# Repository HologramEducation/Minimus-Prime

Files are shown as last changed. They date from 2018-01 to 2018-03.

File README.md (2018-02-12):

# Minimus-Prime

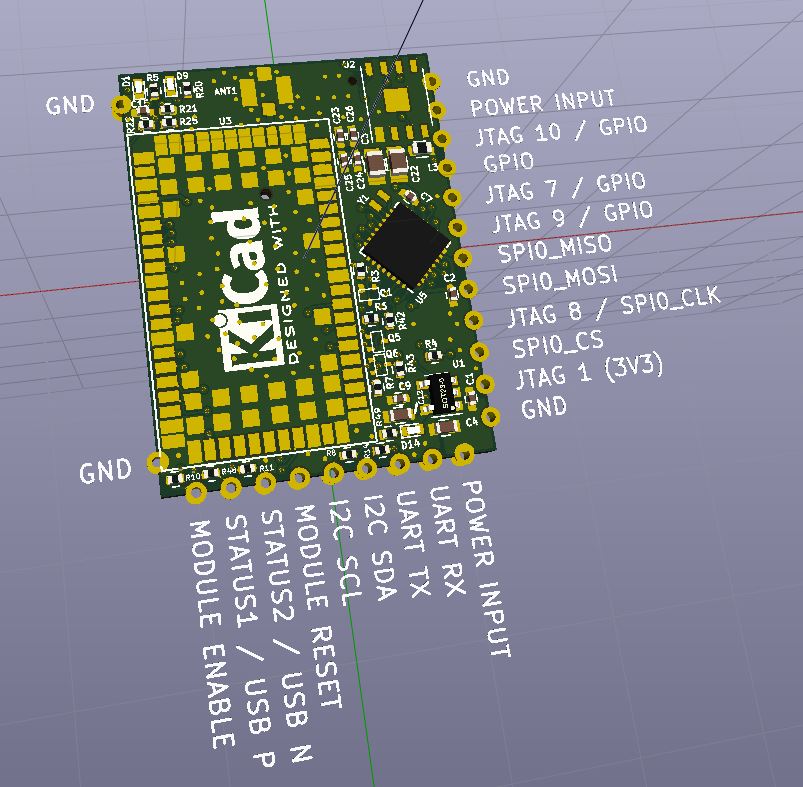
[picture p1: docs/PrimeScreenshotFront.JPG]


## Background

This is an experiment to shrink the logic and support circuitry around a cellular modem to the bare minimum and offer them as a surface mount solderable board. This design will be tested as a lightweight hardware device to connect to Hologram services.

### License

This design is OSHW

## Usage

This device is meant to work with uBlox cellular modems and the Hologram Global SIM card. To get a free SIM and 1 MB of data per month on the cellular plan, check out the [Developer Plan](https://hologram.io/devplan/)

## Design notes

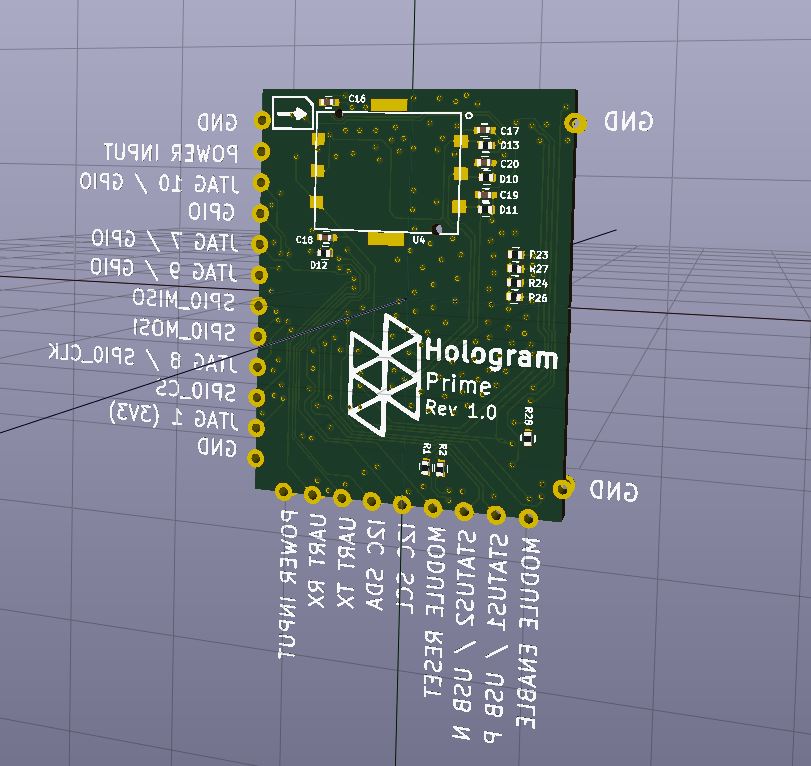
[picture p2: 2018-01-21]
docs/PrimeScreenshotBack.JPG

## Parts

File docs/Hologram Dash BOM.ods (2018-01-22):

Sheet: DASH BOM APPROVAL
SEQ | BID EX | MANUFACTURER P/N | NEDA | MFR | QTY PER
1 | R | A-1JB | 6812 | Amphenol | 1
2 | RN | B2B-PH-SM4-TB(LF)(SN) | NF | JST | 1
3 | R | GRM155R61C104KA88D | 2606 | MURATA | 15
4 | R | 04026D105KAT2A | 7710 | AVX | 3
5 | R | GRM188R71C105KA12D | 2606 | MURATA | 1
6 | R | CL10A225MQ8NNNC | 4139 | SAMSUNG | 4
7 | R | GRM155R71C103KA01D | 2606 | MURATA | 2
8 | R | GRM188R60J106ME84D | 2606 | Murata | 2
9 | R | 04025A150JAT2A | 7710 | AVX/ELCO | 1
10 | R | GRM188R60J226MEA0D | 2606 | MURATA | 3
11 | R | 04025A470JAT2A | 7710 | AVX | 4
12 | R | C0402C560J5GACTU | 7429 | KEMET | 1
13 | R | F950J337MBAAQ2 | 7710 | AVX | 1
14 |  | CX2016DB16000D0WZRC1 | 1412 | AVX | 1
15 | R | ABS05-32.768KHZ-T | 4217 | Abracon | 2
16 |  | CDBQR0230L | 5870 | Comchip | 1
17 | R | CRS08(TE85L,Q,M) | 1062 | Toshiba Semiconductor and Storage | 2
18 | R | BLM18AG121SN1D | 2606 | Murata | 4
19 |  | MKL17Z256VFM4 | 3691 | FREESCALE | 1
20 | R | SF-0603S300-2 | 1506 | Bourns | 1
21 | RN | XFL4020-102MEC | NF | Coilcraft | 1
22 | R | VLMW1500-GS08 | 5680 | VISHAY | 2
23 | * CAN'T GUARANTEE WE WILL BE ABLE TO BUY PART FROM SUPPLIER DUE TO ALLOCATION ISSUES RN | SMLP34RGB2W3 | NF | Rohm | 1
24 | No bid, non book item not availabe to re-sellers | MAX17043G+U | NF | Maxim | 1
25 |  | MCP73871-2CCI/ML | 1389 | MICROCHIP | 1
26 |  | MK22FN1M0AVLH12 | 3691 | Freescale | 1
27 | R | NCP177AMX330TCG | 5236 | On Semi | 1
28 | R | PESD0402-140 | 3685 | Littlefuse | 7
29 | # | 22284180 | 3303 | MOLEX | 2
30 | R | ERJ-2GE0R00X | 1386 | PANASONIC | 1
31 | R | RC0402JR-071KL | 5823 | YAEGO | 1
32 | R | RC0402FR-071ML | 5823 | YAEGO | 1
33 | R | RC0402FR-072KL | 5823 | YAEGO | 1
34 | R | RC0402JR-0710KL | 5823 | YAEGO | 8
35 | R | RC0402FR-0722RL | 5823 | YAEGO | 2
36 | R | RC0402FR-0762KL | 5823 | YAEGO | 1
37 | R | RC0402FR-0775RL | 5823 | YAEGO | 2
38 | R | ERJ-2GEJ104X | 1386 | PANASONIC | 1
39 | R | ERJ-2GEJ121X | 1386 | PANASONIC | 1
40 | R | RC0402FR-07150KL | 5823 | YAEGO | 1
41 | R | ERJ-2GEJ161X | 1386 | PANASONIC | 1
42 | R | ERJ-2GEJ471X | 1386 | PANASONIC | 2
43 | RN | SARA-U260-00S | NF | U-BLOX | 1
44 | RN | SIM8050-6-0-14-01-A | NF | GLOBAL CONNECTOR TECHNOLOGY | 1
45 | R | PTS810SJM250SMTRLFS | 9444 | C&K Components | 2
46 | R | TPS22945DCKR | 7713 | Texas Instruments | 1
47 | R# | TPS63020DSJR | 7713 | TI | 1
48 | R | 10118193-0001LF | 8314 | Amphenol FCI | 1
49 | R | SN74AVC4T774RSVR | 7713 | TI | 1
50 | N# | Hologramh REV 1P2 | NF | PALPILOT | 1
 |  | I have reviewed the Arrow Bill of Material and accept it as
 |  | complete and accurate.
 |  | I have reviewed Arrow Bill of Material and have made
 |  | changes / revisions per the attached. Upon completion
 |  | of said changes / revisions, I accept Arrow Bill of
 |  | Material as complete and accurate. (NOTE: Changes or
 |  | revisions may alter the price and delivery of this proposal.)
 |  | I have reviewed and accept all bid exceptions as indicated
 |  | on Arrow Electronics' Bill of Material.
 |  | # | These items are considered to be acceptable
 |  |  | alternatives to the Approved Vendor List
 |  | N | These items , purchased pursuant to my provided
 |  |  | purchase orders / forecast are designated NCNR
 |  |  | Non-Cancelable Non-Returnable.
 |  | R | These items are to be provided in reeled form.
 |  |  | Residual reeled product due to cancelation or
 |  |  | ECO activity will be NCNR.
 |  | P | These items are to be programmed and are NCNR.
_____________________

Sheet: NOVA BOM APPROVAL
 |  | AMSS Advanced Manufacturing Support Services |  |  |  | Bid Exceptions Key
 |  | BOM APPROVAL |  |  |  | N | NCNR
 |  | HOLOGRAM |  |  |  | R | TAPE & REEL
 |  | BOM HOLOGRAM MODEM REV J |  |  |  | P | PROGRAMMED
 |  |  |  |  |  | # | Different part number than called out on AVL
 |  |  |  |  |  | COP | SUPPLIED BY CUSTOMER AT NO VALUE TO THE BILL OF MATERIALS
CUSTOMER # | SEQ | BID EX | MANUFACTURER P/N | NEDA | MFR | QTY PER | L/T | MIN
CON-0006 | 1 | R | A-1JB | 6812 | Amphenol | 1 | 24 | 50000
CAP-0004 | 2 | R | GRM155R61C104KA88D | 2606 | MURATA | 3 | 38 | 10000
CAP-0002 | 3 | R | CL10A225MQ8NNNC | 4139 | SAMSUNG | 1 | 16 | 4000
CAP-0016 | 4 | R | GRM155R71C103KA01D | 2606 | MURATA | 3 | 14 | 10000
CAP-0007 | 5 | R | GRM188R60J106ME84D | 2606 | Murata | 1 | 16 | 4000
CAP-0011 | 6 | R | 04025A150JAT2A | 7710 | AVX/ELCO | 3 | 20 | 10000
CAP-0008 | 7 | R | GRM188R60J226MEA0D | 2606 | MURATA | 3 | 38 | 4000
CAP-0010 | 8 | R | 04025A470JAT2A | 7710 | AVX | 4 | 20 | 30000
CAP-0009 | 9 | R | C0402C560J5GACTU | 7429 | KEMET | 3 | 8 | 10000
CAP-0012 | 10 | R | F950J337MBAAQ2 | 7710 | AVX | 3 | 9 | 2000
IND-0005 | 11 | R | BLM18KG121TN1D | 2606 | Murata | 1 | 6 | 4000
IND-0003 | 12 | RN | XFL4020-102MEC | NF | Coilcraft | 1 | STK-6 | 1000
DIO-0007 | 13 | R | VLMB1500-GS08 | 5680 | VISHAY | 1 | 12 | 9000
DIO-0008 | 14 | R | VLMS1500-GS08 | 5680 | VISHAY | 1 | 10 | 9000
DIO-0009 | 15 | R | PESD0402-140 | 3685 | Littlefuse | 7 | 8 | 10000
RES-0020 | 16 | R | RC0603JR-070RL | 5823 | YAEGO | 1 | 18 | 5000
RES-0014 | 17 | R | RC0402FR-071ML | 5823 | YAEGO | 1 | 8 | 50000
RES-0019 | 18 | R | RC0402FR-073KL | 5823 | YAEGO | 2 | 18 | 50000
RES-0008 | 19 | R | RC0402JR-0710KL | 5823 | YAEGO | 4 | 18 | 50000
RES-0016 | 20 | R | RC0402FR-0722RL | 5823 | YAEGO | 2 | 18 | 50000
RES-0003 | 21 | R | ERJ-2GEJ104X | 1386 | PANASONIC | 1 | 54 | 50000
RES-0004 | 22 | R | RC0402FR-07150KL | 5823 | YAEGO | 1 | 18 | 50000
RES-0006 | 23 | R | ERJ-2GEJ471X | 1386 | PANASONIC | 1 | 54 | 50000
IC-0007 | 24 | RN | SARA-U260-00S | NF | U-BLOX | 1 | STK-17 | 250
CON-0007 | 25 | RN | SIM8050-6-0-14-01-A | NF | GLOBAL CONNECTOR TECHNOLOGY | 1 | STK-10 | 1500
IC-0013 | 26 | R# | TPS63020DSJR | 7713 | TI | 1 | 12 | 3000
IC-0014 | 27 | R | MMBT3904LT1G | 8614 | ON Semiconductor | 4 | 45 | 3000
CON-0008 | 28 | R | 480372200 | 3303 | MOLEX | 1 | 6 | 7200
PCB | 29 | N# | Hologram_Nova REV J | NF | PALPILOT | 1 | 7 | 1008
{Initial one} |  |  | I have reviewed the Arrow Bill of Material and accept it as
______________ |  |  | complete and accurate.
______________ |  |  | I have reviewed Arrow Bill of Material and have made
 |  |  | changes / revisions per the attached. Upon completion
 |  |  | of said changes / revisions, I accept Arrow Bill of
 |  |  | Material as complete and accurate. (NOTE: Changes or
 |  |  | revisions may alter the price and delivery of this proposal.)
BID EXCEPTIONS: These items must be reviewed and approved. {Initial}
______________ |  |  | I have reviewed and accept all bid exceptions as indicated
 |  |  | on Arrow Electronics' Bill of Material.
 |  |  | # | These items are considered to be acceptable
 |  |  |  | alternatives to the Approved Vendor List
 |  |  | N | These items , purchased pursuant to my provided
 |  |  |  | purchase orders / forecast are designated NCNR
 |  |  |  | Non-Cancelable Non-Returnable.
 |  |  | R | These items are to be provided in reeled form.
 |  |  |  | Residual reeled product due to cancelation or
 |  |  |  | ECO activity will be NCNR.
 |  |  | P | These items are to be programmed and are NCNR.
___________________________________
Signature
___________________________________
Title
Date: | _____________________
PLEASE INCLUDE ALL PAGES WHEN RETURNING THE ATTACHMENT B.
ANY INFORMATION SUPPLIED BY ARROW IN RELATION TO A PARTICULAR PART'S ROHS/LEAD-FREE COMPLIANCE OR NON-COMPLIANCE IS PROVIDED "AS-IS" WITHOUT ANY WARRANTY WHATSOEVER, SUCH AS ALL WARRANTIES IMPLIED IN LAW, INCLUDING THE WARRANTIES OF MERCHANTABILITY AND SUITABILITY FOR A PARTICULAR PURPOSE. USE OF THE DATA IS AT CUSTOMER'S SOLE RISK.

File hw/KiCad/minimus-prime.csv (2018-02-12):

Refs | Link | MPN | Populated | datasheet | footprint | value
ANT1 | https://www.digikey.com/product-detail/en/amphenol-rf-division/A-1JB/ARF1579CT-ND/1196264 | A-1JB | Y |  | beaglephone-pocket:A-1JB | A-1JB
C1, C2, C7, C9, C16, C24 | https://www.digikey.com/product-detail/en/murata-electronics-north-america/GRM155R71C104KA88J/490-6328-1-ND/3845525 | GRM155R71C104KA88J | Y |  | Capacitors_SMD:C_0402 | 100n
C4, C12 | https://www.digikey.com/product-detail/en/murata-electronics-north-america/GRM188R60J226MEA0D/490-7611-1-ND/4280544 | GRM188R60J226MEA0D | Y |  | Capacitors_SMD:C_0603 | 22U
C15, C17-C20 | https://www.digikey.com/product-detail/en/murata-electronics-north-america/GRM1555C1H470JA01D/490-5942-1-ND/3721299 | GRM1555C1H470JA01 | N |  | Capacitors_SMD:C_0402 | 47p
C3, C22 | https://www.digikey.com/product-detail/en/samsung-electro-mechanics/CL21A226MOCLRNC/1276-6780-1-ND/5961639 | CL21A226MOCLRNC | Y |  | Capacitors_SMD:C_0805 | 22U
C23 | https://www.digikey.com/product-detail/en/murata-electronics-north-america/GRM1555C1H100JA01D/490-5921-1-ND/3721278 | GRM1555C1H100JA01D | Y |  | Capacitors_SMD:C_0402 | 10n
C25 | https://www.digikey.com/product-detail/en/murata-electronics-north-america/GRM1555C1H560JA01D/490-1288-1-ND/587890 | GRM1555C1H560JA01D | Y |  | Capacitors_SMD:C_0402 | 56p
C26 | https://www.digikey.com/product-detail/en/murata-electronics-north-america/GJM1555C1H150JB01D/490-3117-1-ND/702383 | GJM1555C1H150JB01D | Y |  | Capacitors_SMD:C_0402 | 15p
D1, D14 | https://www.digikey.com/product-detail/en/vishay-semiconductor-opto-division/VLMS1500-GS08/VLMS1500-GS08CT-ND/3504675 | VLMS1500-GS08 | Y |  | LEDs:LED_0402 | Red LED
D10-D13 | https://www.digikey.com/product-detail/en/littelfuse-inc/PESD0402-140/PESD0402-140CT-ND/1968526 | PESD0402-140 | N |  | Resistors_SMD:R_0402 | PESD0402
D9 | https://www.digikey.com/product-detail/en/vishay-semiconductor-opto-division/VLMB1500-GS08/VLMB1500-GS08TR-ND/3504677 | VLMB1500-GS08 | Y |  | LEDs:LED_0402 | Blue LED
J1 |  |  | N |  |  | Minimus_Prime_Outline
L3 | https://www.digikey.com/product-detail/en/murata-electronics-north-america/BLM18AG121SN1D/490-1011-1-ND/584459 | BLM18AG121SN1D | Y |  | Resistors_SMD:R_0603 | FB
Q1, Q5, Q6 | https://www.digikey.com/product-detail/en/central-semiconductor-corp/CMUDM7004-TR/CMUDM7004-CT-ND/5324586 | CMUDM7004 | Y | https://www.centralsemi.com/get_document.php?cmp=1&mergetype=pd&mergepath=pd&pdf_id=CMUDM7004.PDF | minimus-prime:SOT-523 | CMUDM7004
R1, R2, R23, R24, R26, R27, R28 | https://www.digikey.com/product-detail/en/yageo/RC0402JR-070RL/311-0.0JRCT-ND/729353 | RC0402JR-070RL | N |  | Resistors_SMD:R_0402 | 0
R4, R10, R11, R48 | https://www.digikey.com/product-detail/en/yageo/RC0402JR-070RL/311-0.0JRCT-ND/729353 | RC0402JR-070RL | Y |  | Resistors_SMD:R_0402 | 0
R6-R8, R14, R42, R43 | https://www.digikey.com/product-detail/en/yageo/RC0402JR-0710KL/311-10KJRTR-ND/726418 | RC0402JR-0710KL | Y |  | Resistors_SMD:R_0402 | 10K
R5, R20, R49 | https://www.digikey.com/product-detail/en/yageo/RC0402JR-073KL/311-3.0KJRCT-ND/729400 | RC0402JR-073KL | Y |  | Resistors_SMD:R_0402 | 3K
R21, R22 | https://www.digikey.com/product-detail/en/yageo/RC0402FR-07100KL/311-100KLRCT-ND/729473 | RC0402FR-07100KL | N |  | Resistors_SMD:R_0402 | 100K
R3, R25 | https://www.digikey.com/product-detail/en/yageo/RC0402FR-07100KL/311-100KLRCT-ND/729473 | RC0402FR-07100KL | Y |  | Resistors_SMD:R_0402 | 100K
TP1 |  |  | N |  |  | TEST
U1 | https://www.digikey.com/product-detail/en/texas-instruments/TLV70033DDCR/296-27937-1-ND/2440840 | TLV70033DDCR | Y | http://www.ti.com/lit/ds/slvsa00e/slvsa00e.pdf | TO_SOT_Packages_SMD:SOT-23-5 | TLV700
U2 |  | eSIM | Y |  | Housings_DFN_QFN:DFN-8-1EP_6x5mm_Pitch1.27mm_SmallFlag | eSIM
U3 | https://www.digikey.com/product-detail/en/u-blox-america-inc/SARA-U260-00S/672-1022-1-ND/6150685 | SARA-U260-00S | Y |  | beaglephone-pocket:SARA-G3-U2 | SARA-U260
U4 | http://www.newark.com/global-connector-technology/sim8050-6-0-14-01-a/connector-nano-sim-card-6-position/dp/94W2768 | SIM8050-6-0-14-01-A | N | http://www.farnell.com/datasheets/2342939.pdf | beaglephone-pocket:SIM8050-6-0-14-01-A | SIM-CARD-HOLDER
U5 | https://www.digikey.com/product-detail/en/nxp-usa-inc/MKL17Z256VFM4/MKL17Z256VFM4-ND/4988915 | MKL17Z256VFM4 | Y | http://cache.freescale.com/files/32bit/doc/data_sheet/KL17P64M48SF6.pdf | Housings_DFN_QFN:QFN-32-1EP_5x5mm_Pitch0.5mm | MKL17Z256VFM4
Y1 | https://www.digikey.com/product-detail/en/abracon-llc/ABS05-32.768KHZ-T/535-11899-1-ND/3508067 | ABS05-32.768KHZ-T | Y | http://www.abracon.com/Resonators/ABS05.pdf | minimus-prime:ABS05 | ABS5

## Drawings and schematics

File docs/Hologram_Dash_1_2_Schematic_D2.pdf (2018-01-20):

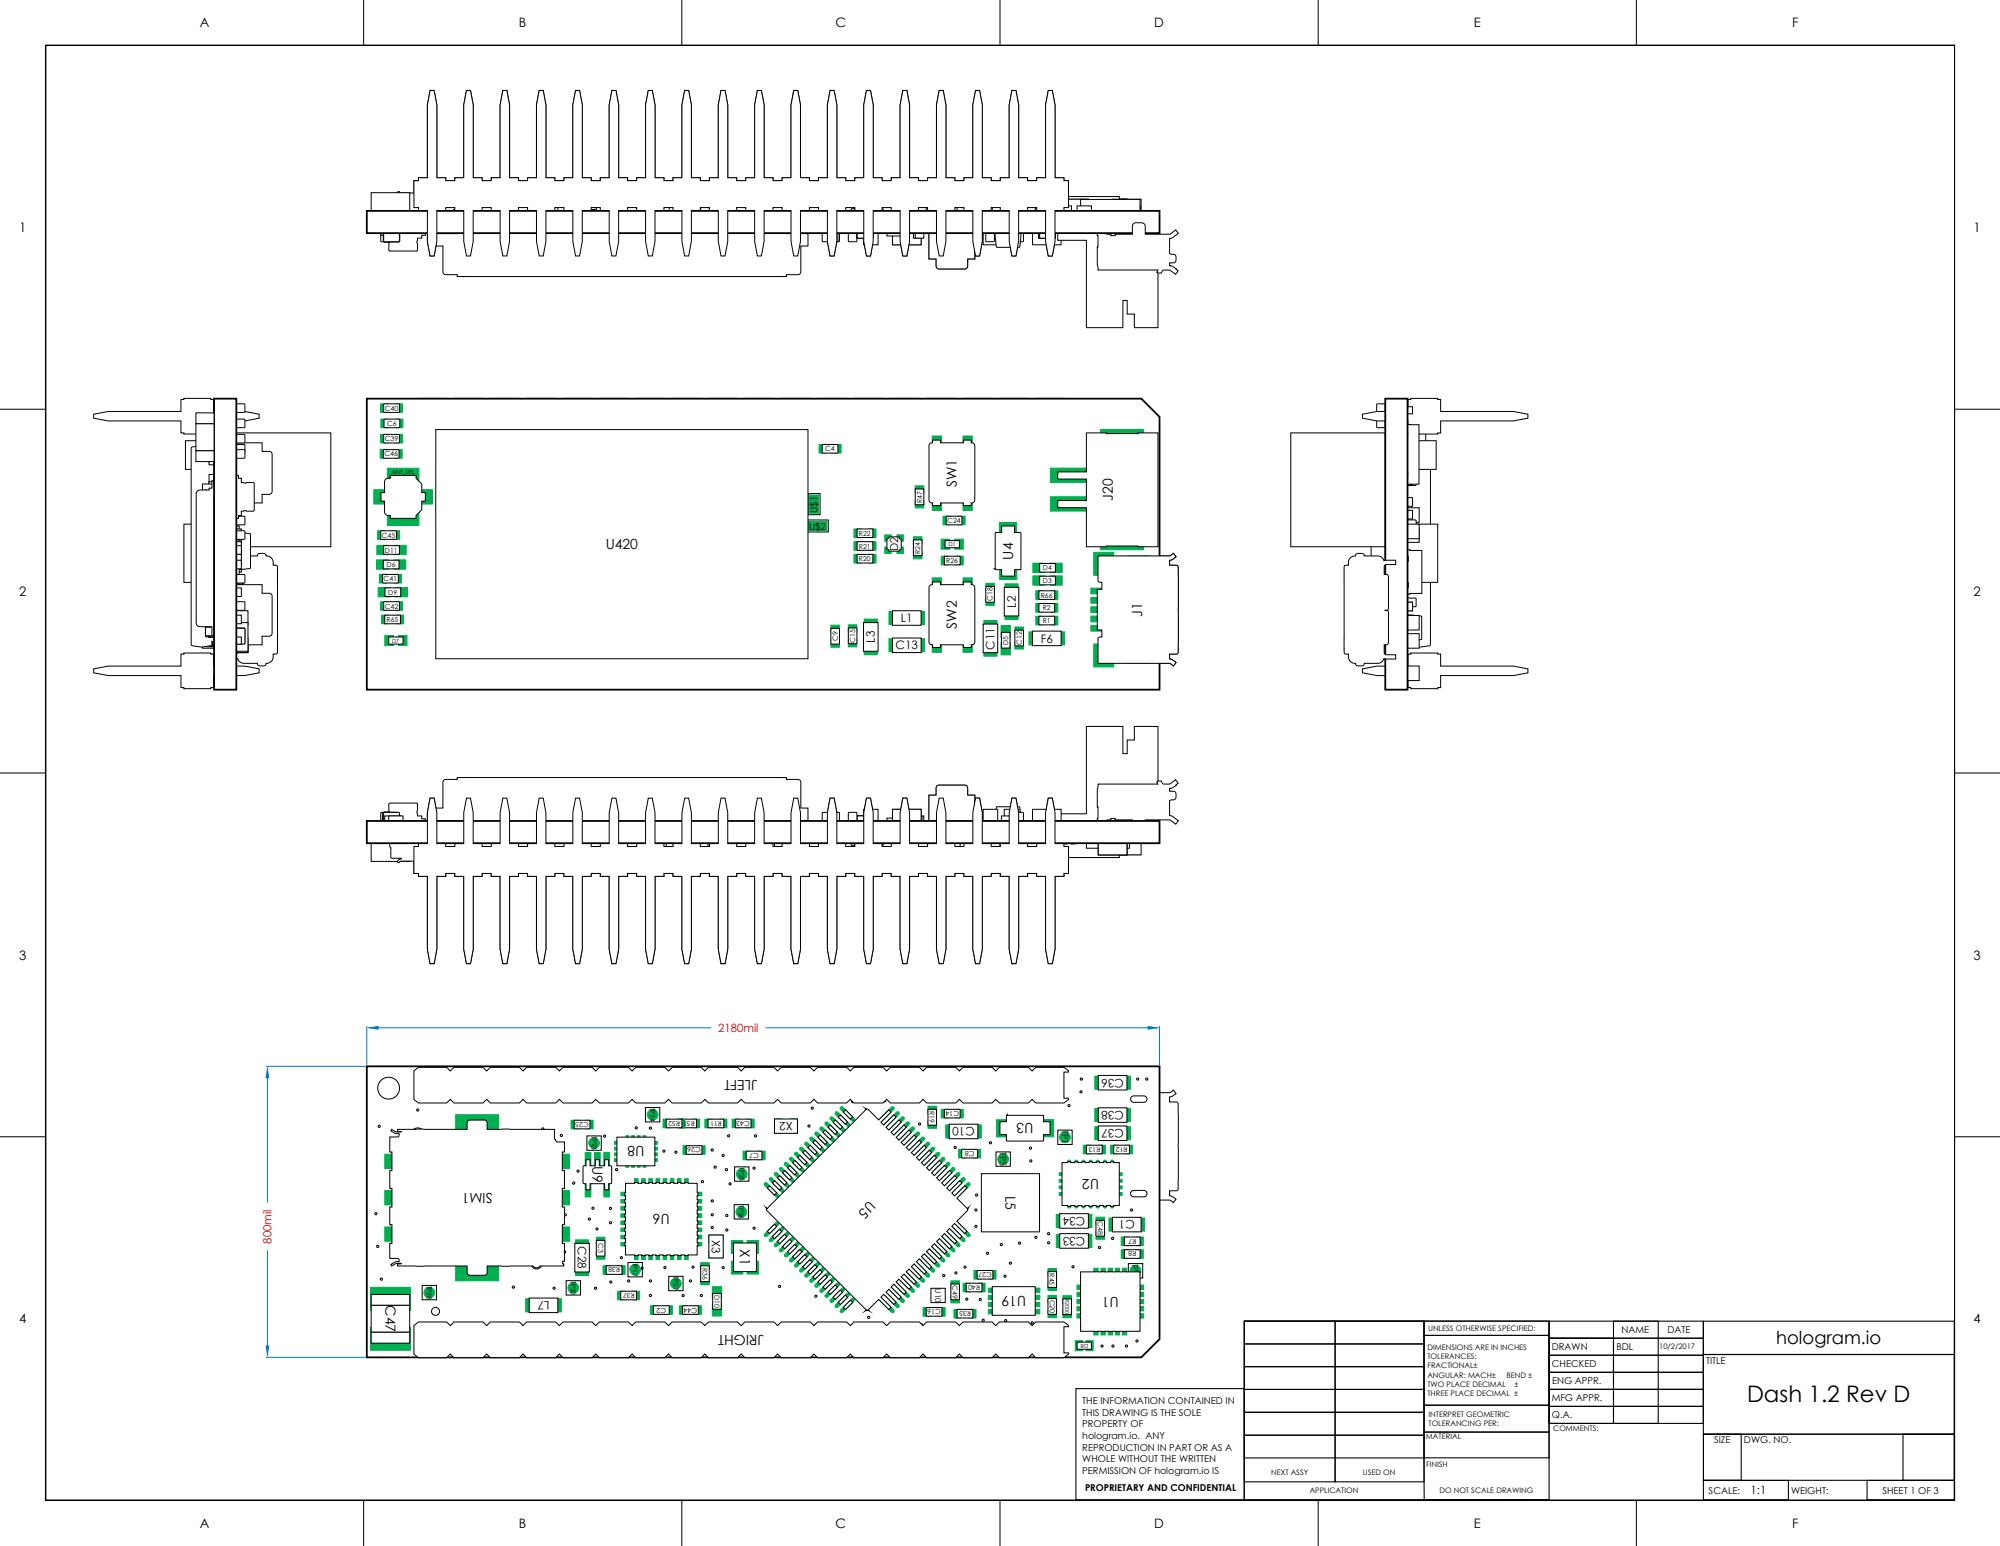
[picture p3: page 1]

DIMENSIONS ARE IN INCHES
TOLERANCES:
FRACTIONAL±
ANGULAR: MACH± BEND ±
TWO PLACE DECIMAL ±
THREE PLACE DECIMAL ±

THE INFORMATION CONTAINED IN
THIS DRAWING IS THE SOLE
PROPERTY OF
hologram.io. ANY
REPRODUCTION IN PART OR AS A
WHOLE WITHOUT THE WRITTEN
PERMISSION OF hologram.io IS
PROPRIETARY AND CONFIDENTIAL

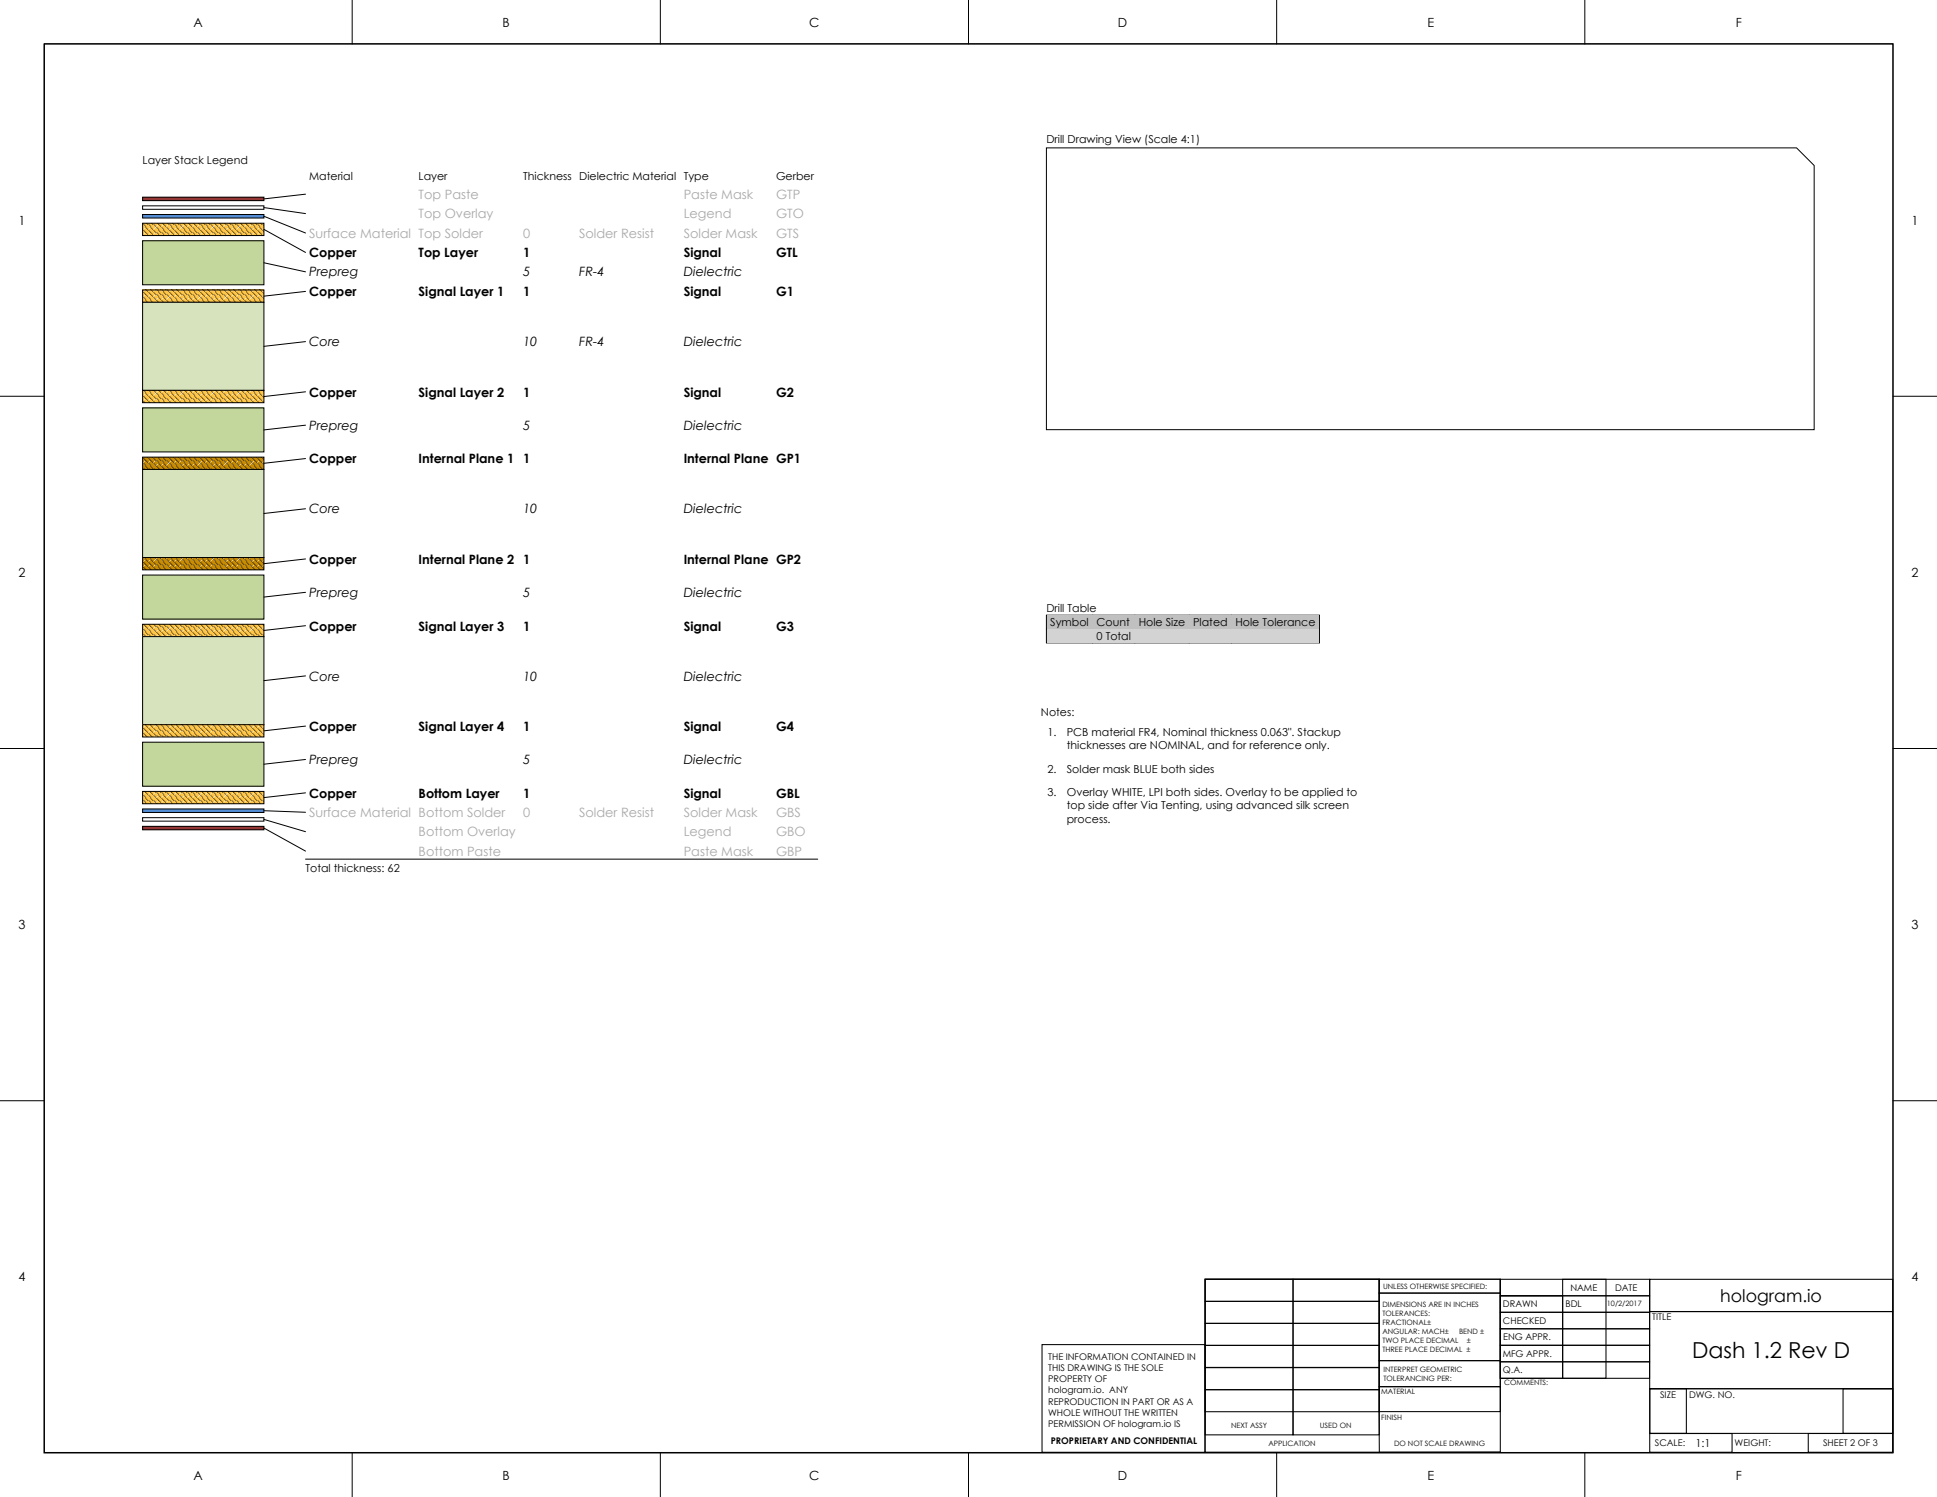
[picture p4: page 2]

Drill Drawing View (Scale 4:1)

Symbol | Count | Hole Size | Plated | Hole Tolerance

0 Total

Notes:
PCB material FR4, Nominal thickness 0.063". Stackup
thicknesses are NOMINAL, and for reference only.
2. Solder mask BLUE both sides
Overlay WHITE, LPI both sides. Overlay to be applied to
top side after Via Tenting, using advanced silk screen
process.

UNLESS OTHERWISE SPECIFIED: | | NAME | DATE 10/2/2017 | hologram.io
DIMENSIONS ARE IN INCHES TOLERANCES: FRACTIONAL± ANGULAR: MACH± BEND ± TWO PLACE DECIMAL ± THREE PLACE DECIMAL ± | DRAWN | BDL

CHECKED | | | TITLE Dash 1.2 Rev D
ENG APPR.

THE INFORMATION CONTAINED IN THIS DRAWING IS THE SOLE | | | MFG APPR.

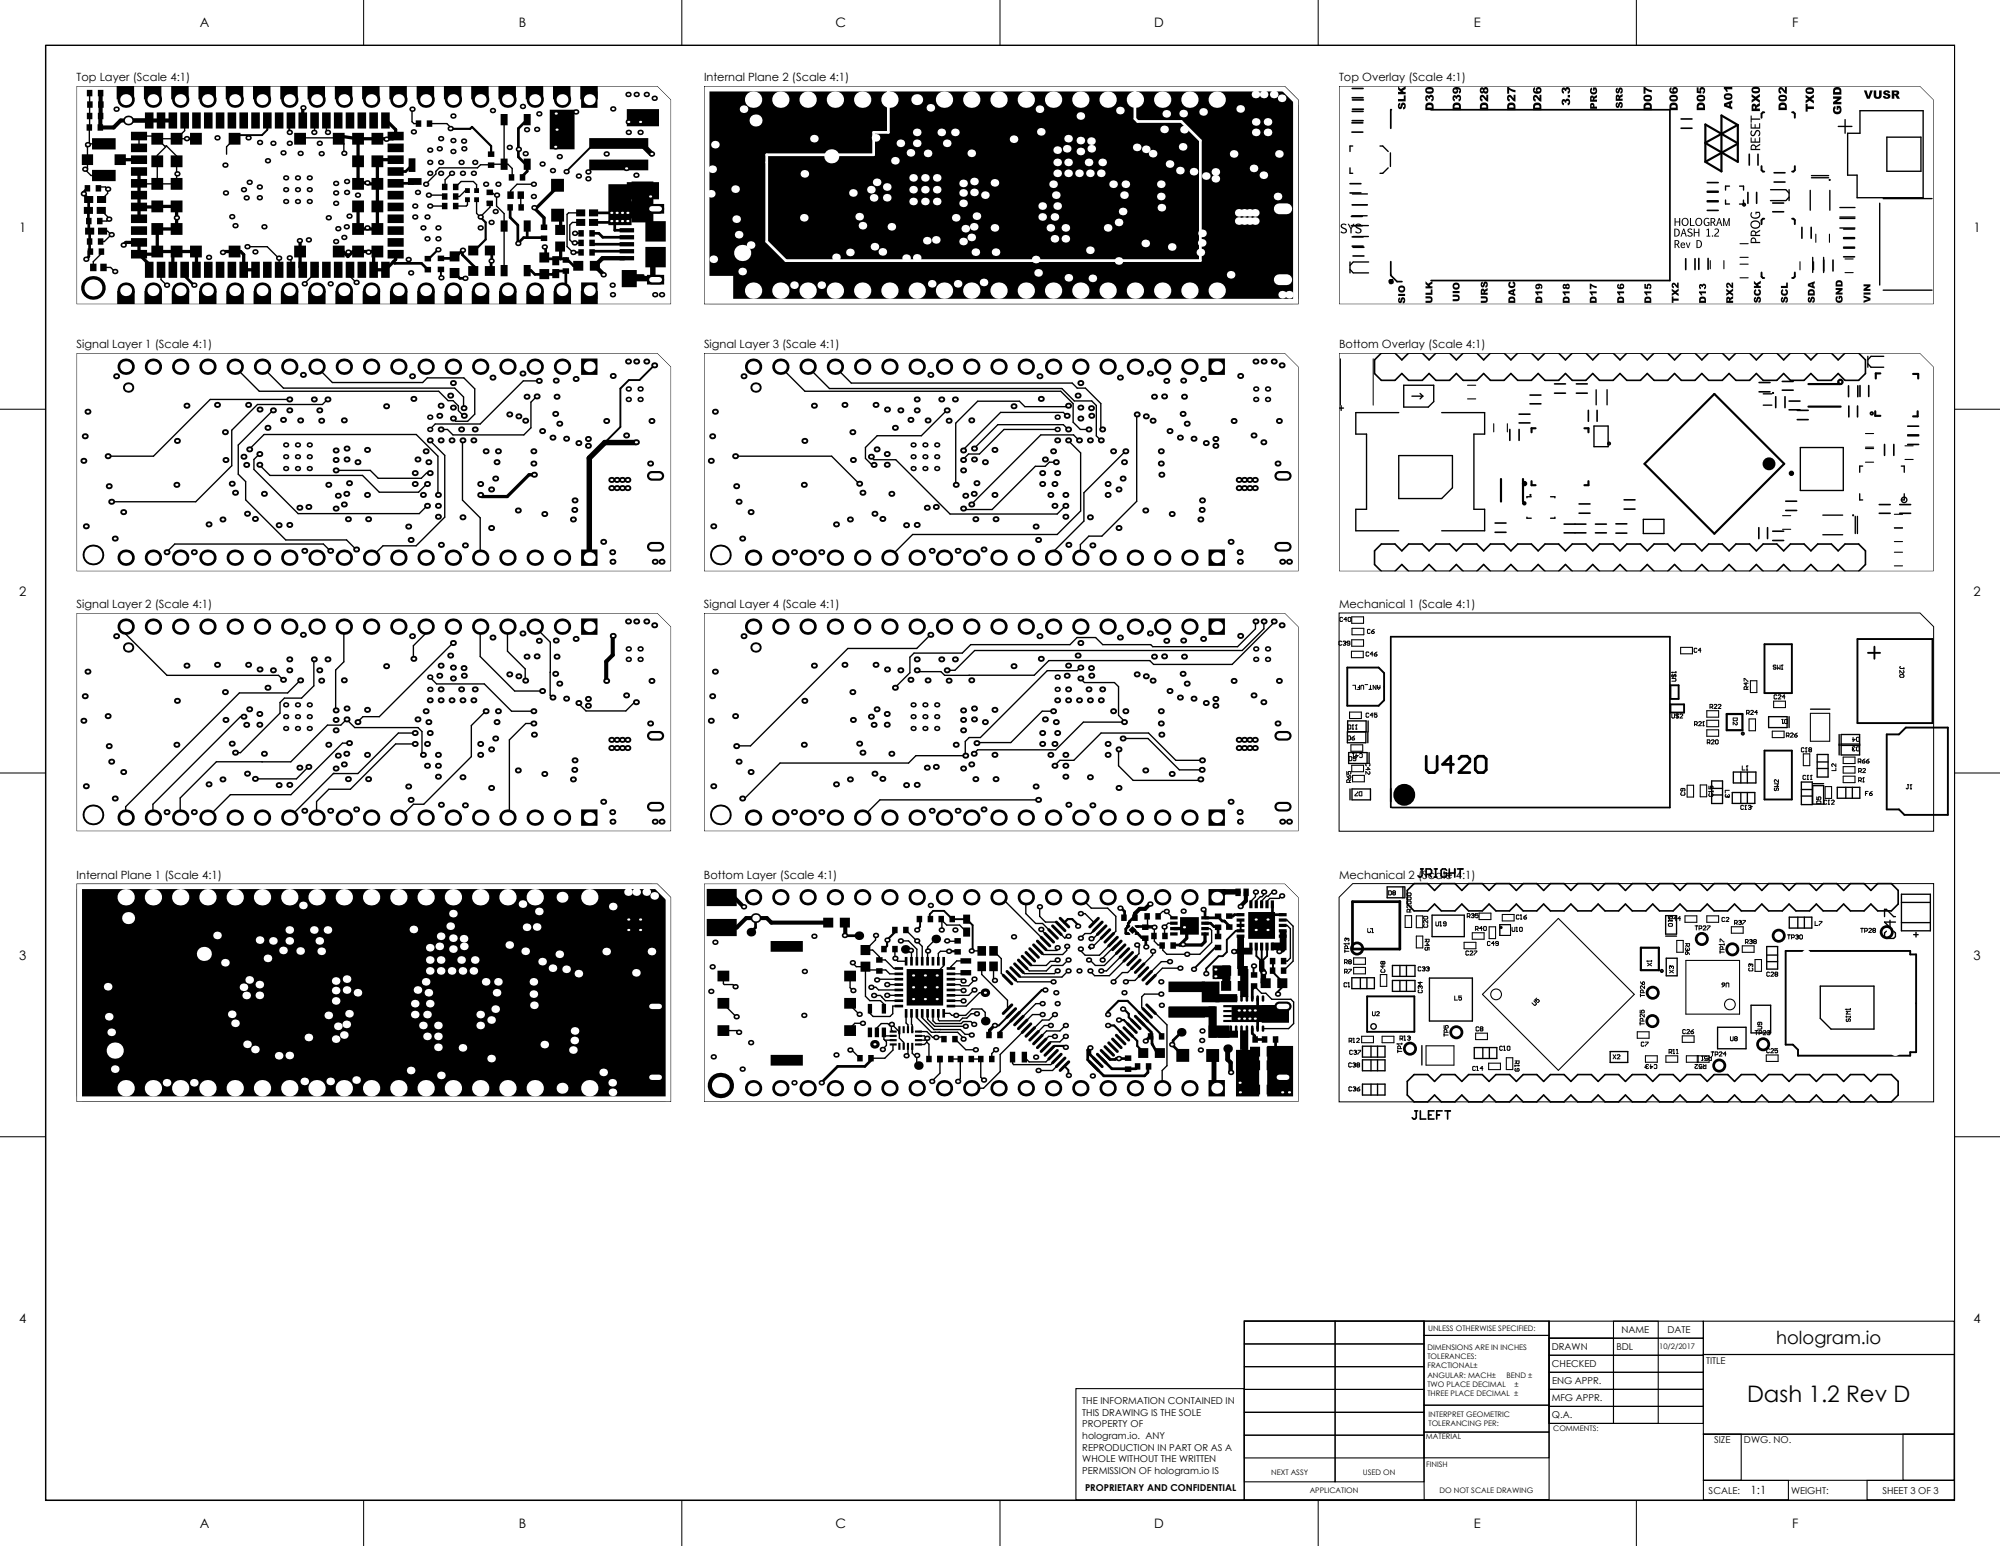
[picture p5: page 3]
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

CHECKED | | | TITLE Dash 1.2 Rev D
ENG APPR.

THE INFORMATION CONTAINED IN THIS DRAWING IS THE SOLE | | | MFG APPR.

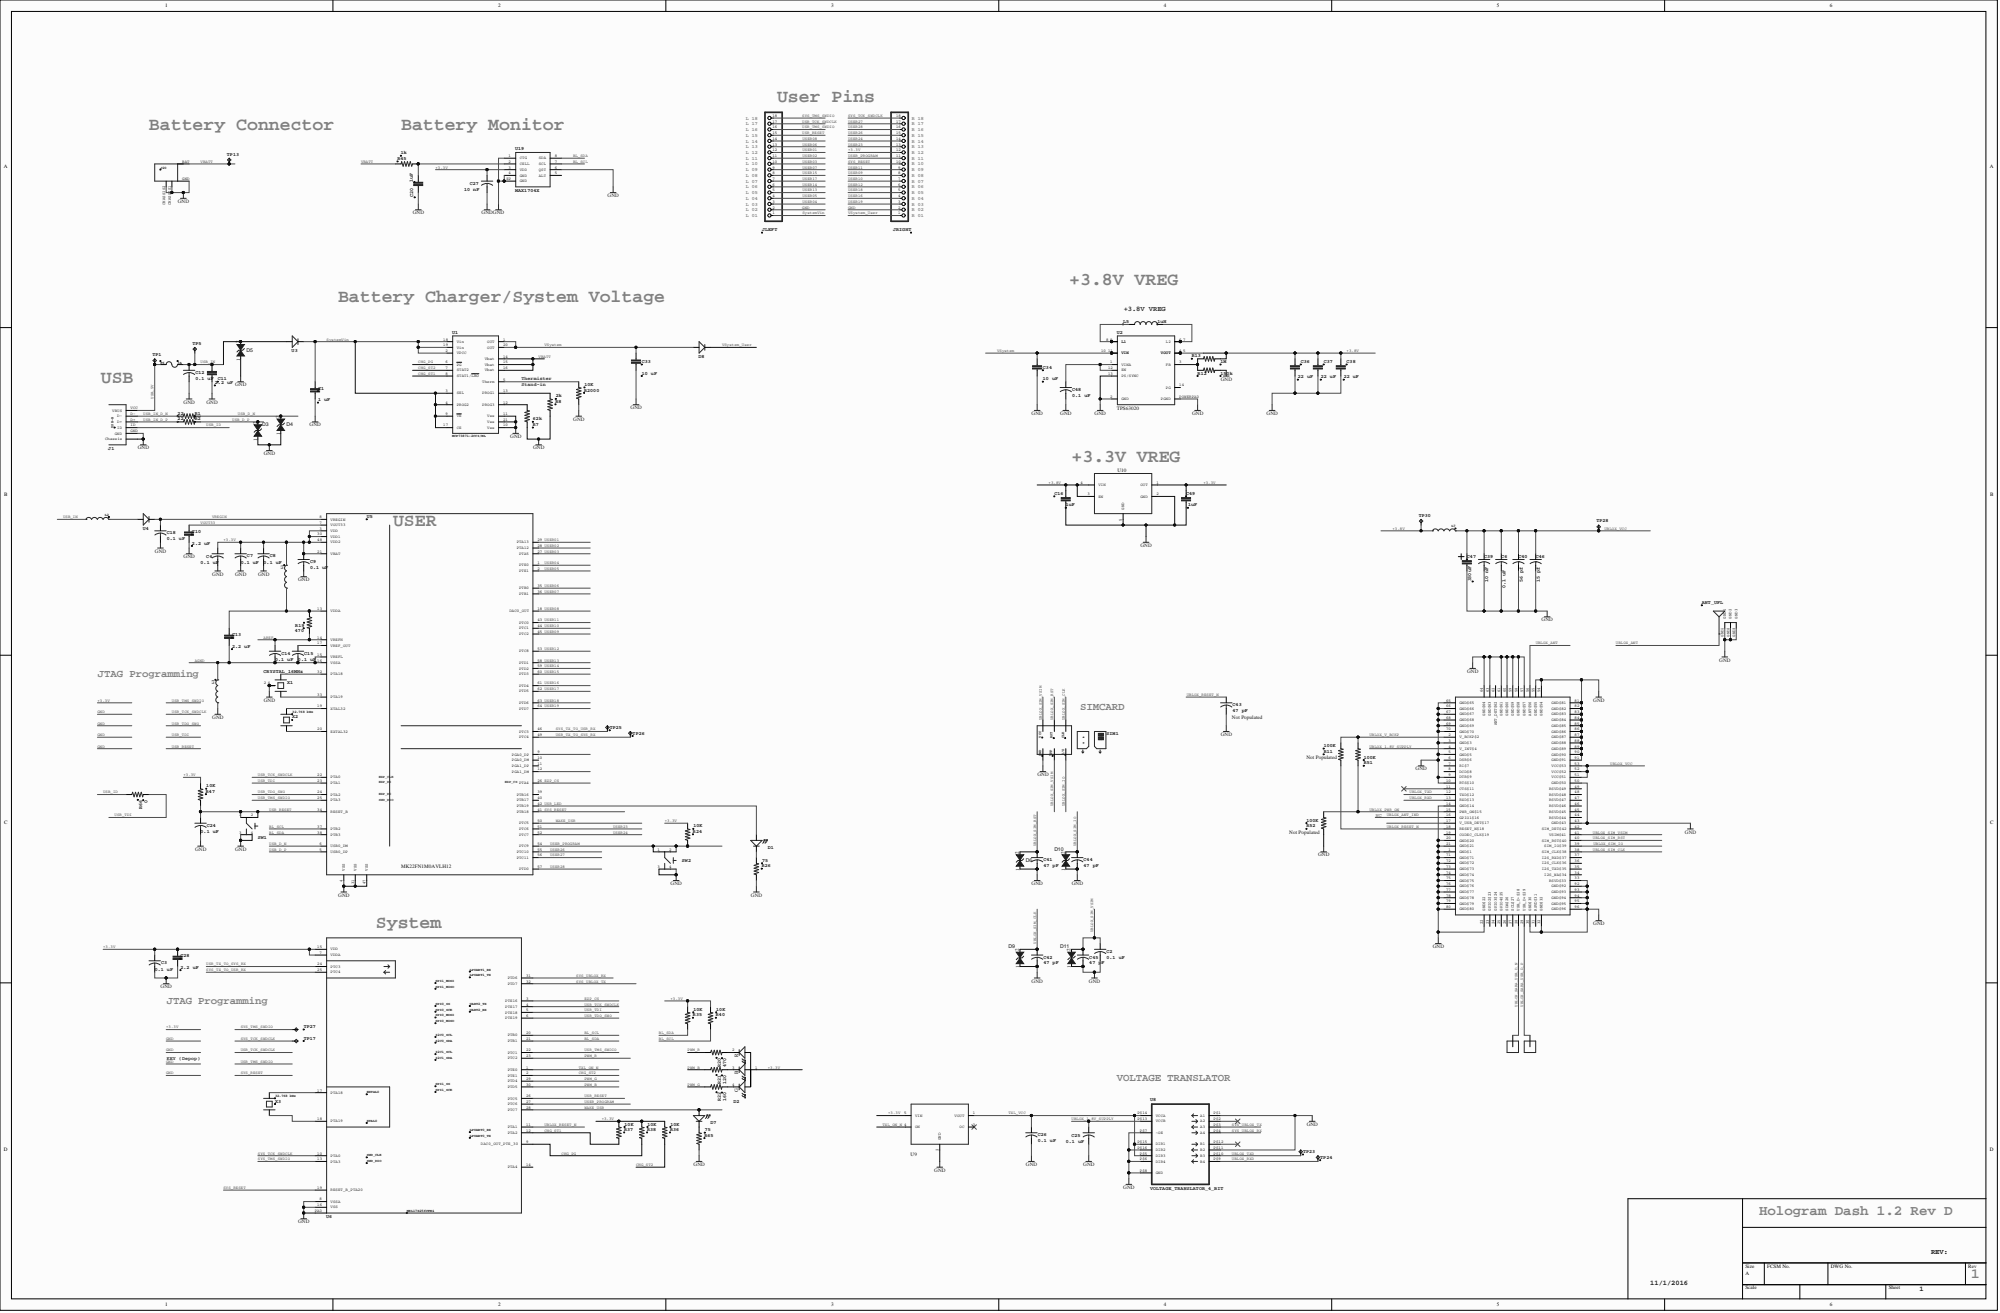
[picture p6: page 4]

Battery Charger/System Voltage

PROG2 4

VOUT33 | VOUT33 7

VDD 3
VDD1 30

VREF_OUT 17

VSSA 16

GND$57 57 GND$58 58 GND$59 59 GND$60 60 GND$61 61

DSR$6 6

UBLOX_TXD UBLOX_RXD | | DCD$8 8

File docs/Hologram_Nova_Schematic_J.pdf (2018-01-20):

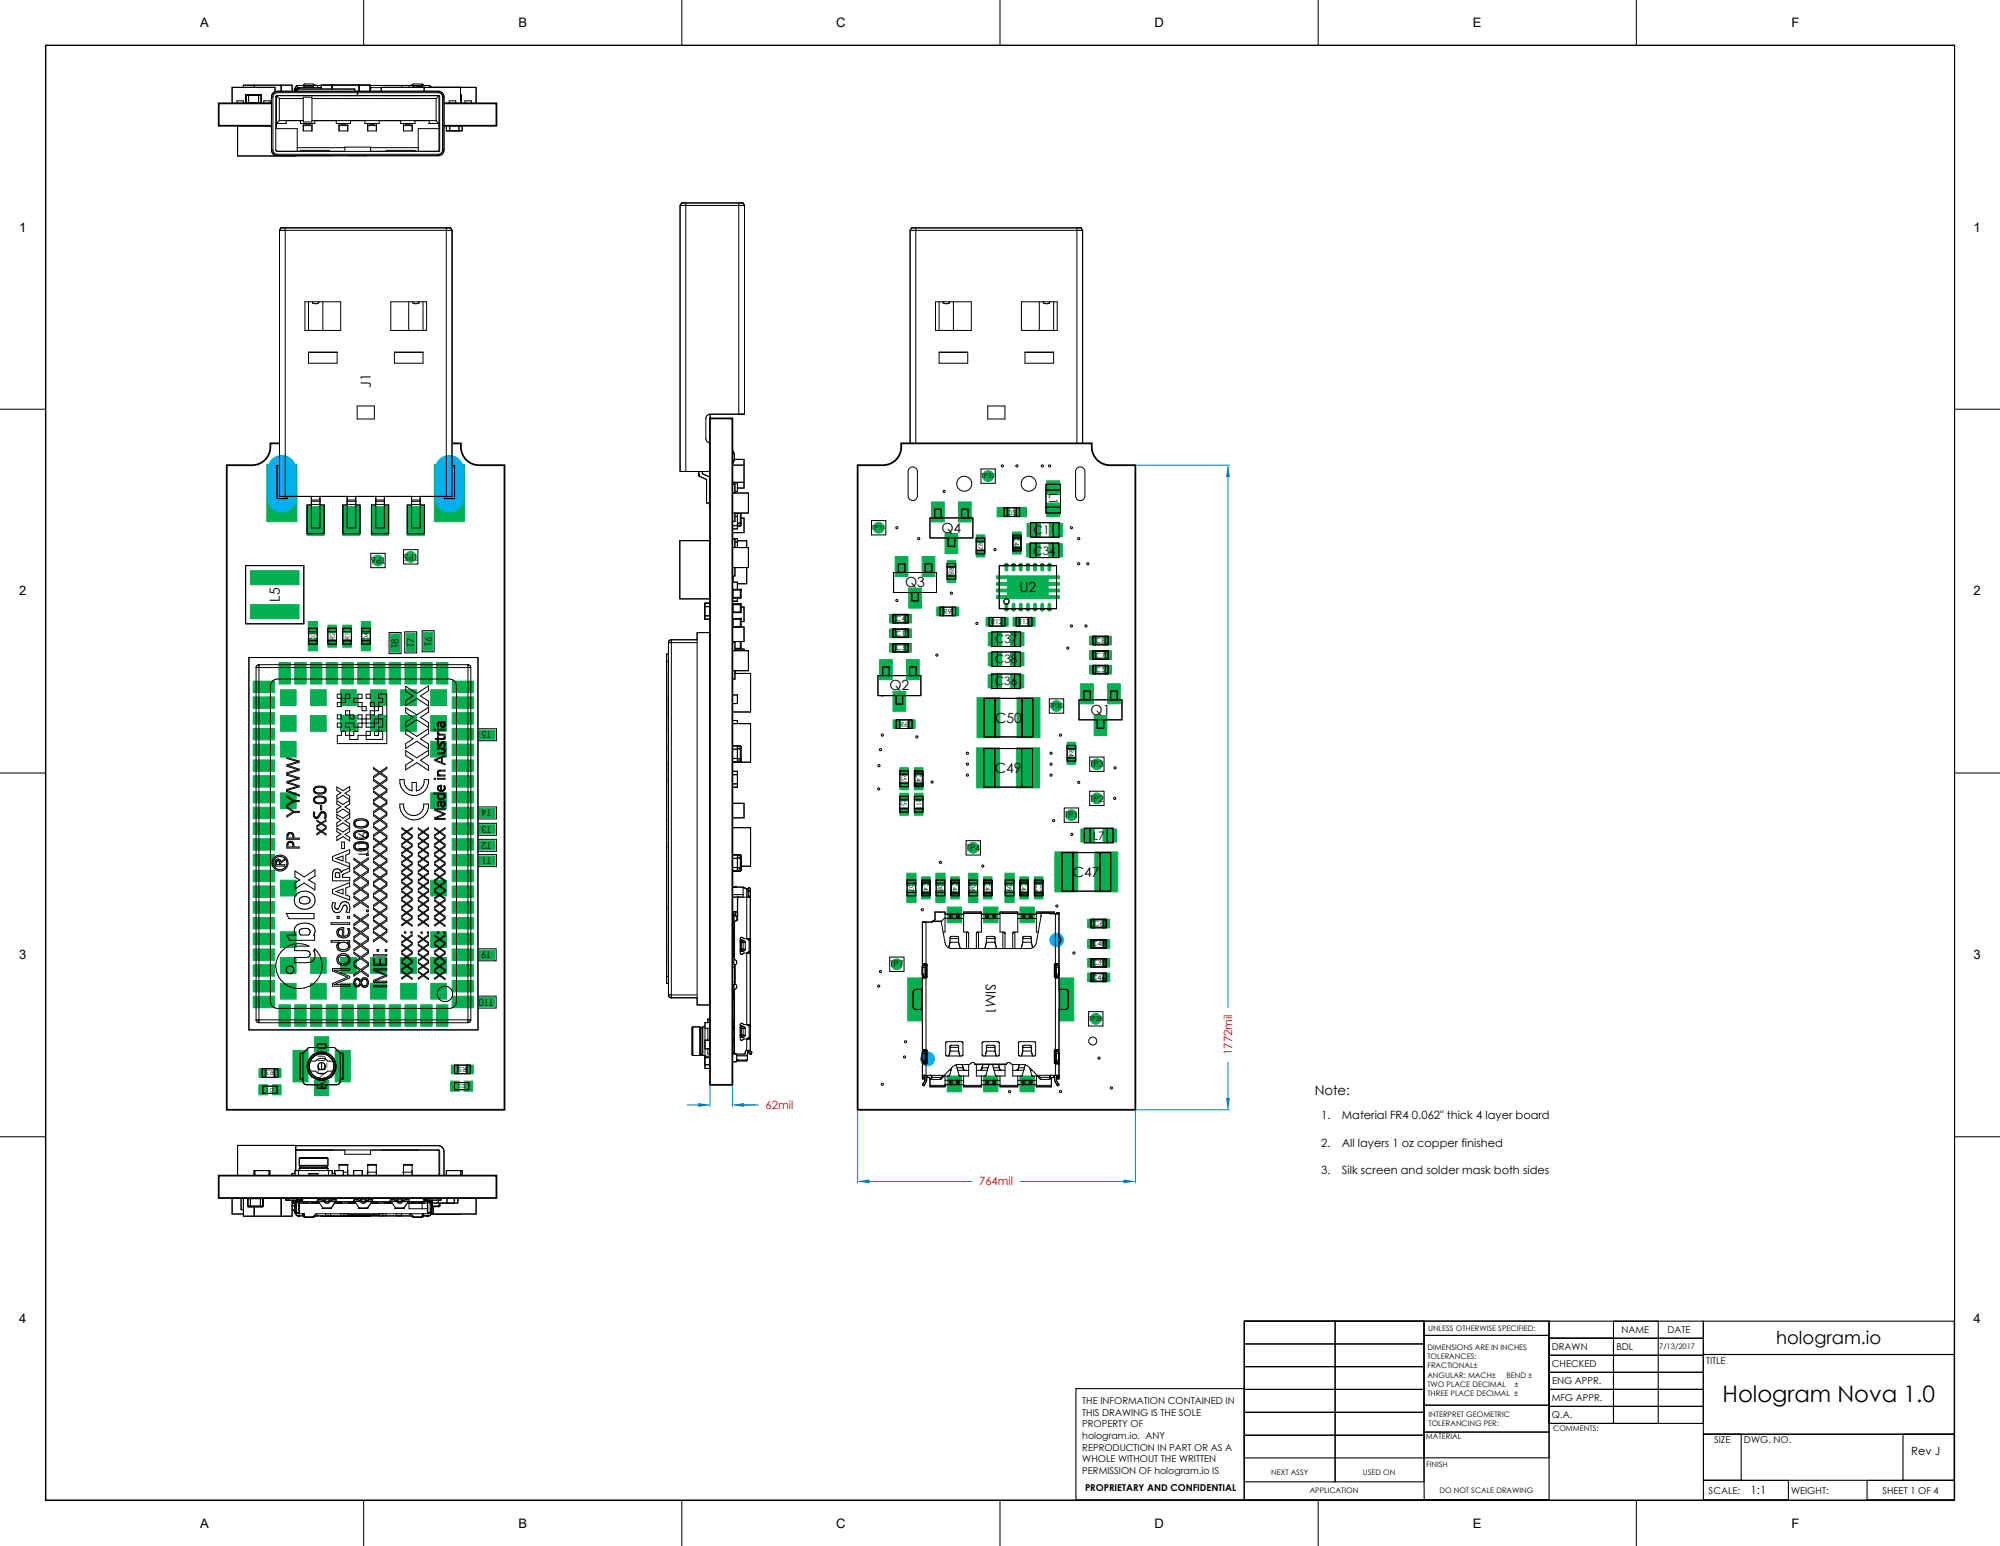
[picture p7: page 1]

1. Material FR4 0.062" thick 4 layer board

2. All layers 1 oz copper finished

3. Silk screen and solder mask both sides

UNLESS OTHERWISE SPECIFIED: | | NAME | DATE 7/13/2017 | hologram.io
DIMENSIONS ARE IN INCHES TOLERANCES: FRACTIONAL± ANGULAR: MACH± BEND ± TWO PLACE DECIMAL ± THREE PLACE DECIMAL ± | DRAWN | BDL

CHECKED | | | TITLE Hologram Nova 1.0
ENG APPR.

THE INFORMATION CONTAINED IN THIS DRAWING IS THE SOLE PROPERTY OF hologram.io. ANY REPRODUCTION IN PART OR AS A WHOLE WITHOUT THE WRITTEN PERMISSION OF hologram.io IS PROPRIETARY AND CONFIDENTIAL | | | MFG APPR.

INTERPRET GEOMETRIC TOLERANCING PER: | Q.A.

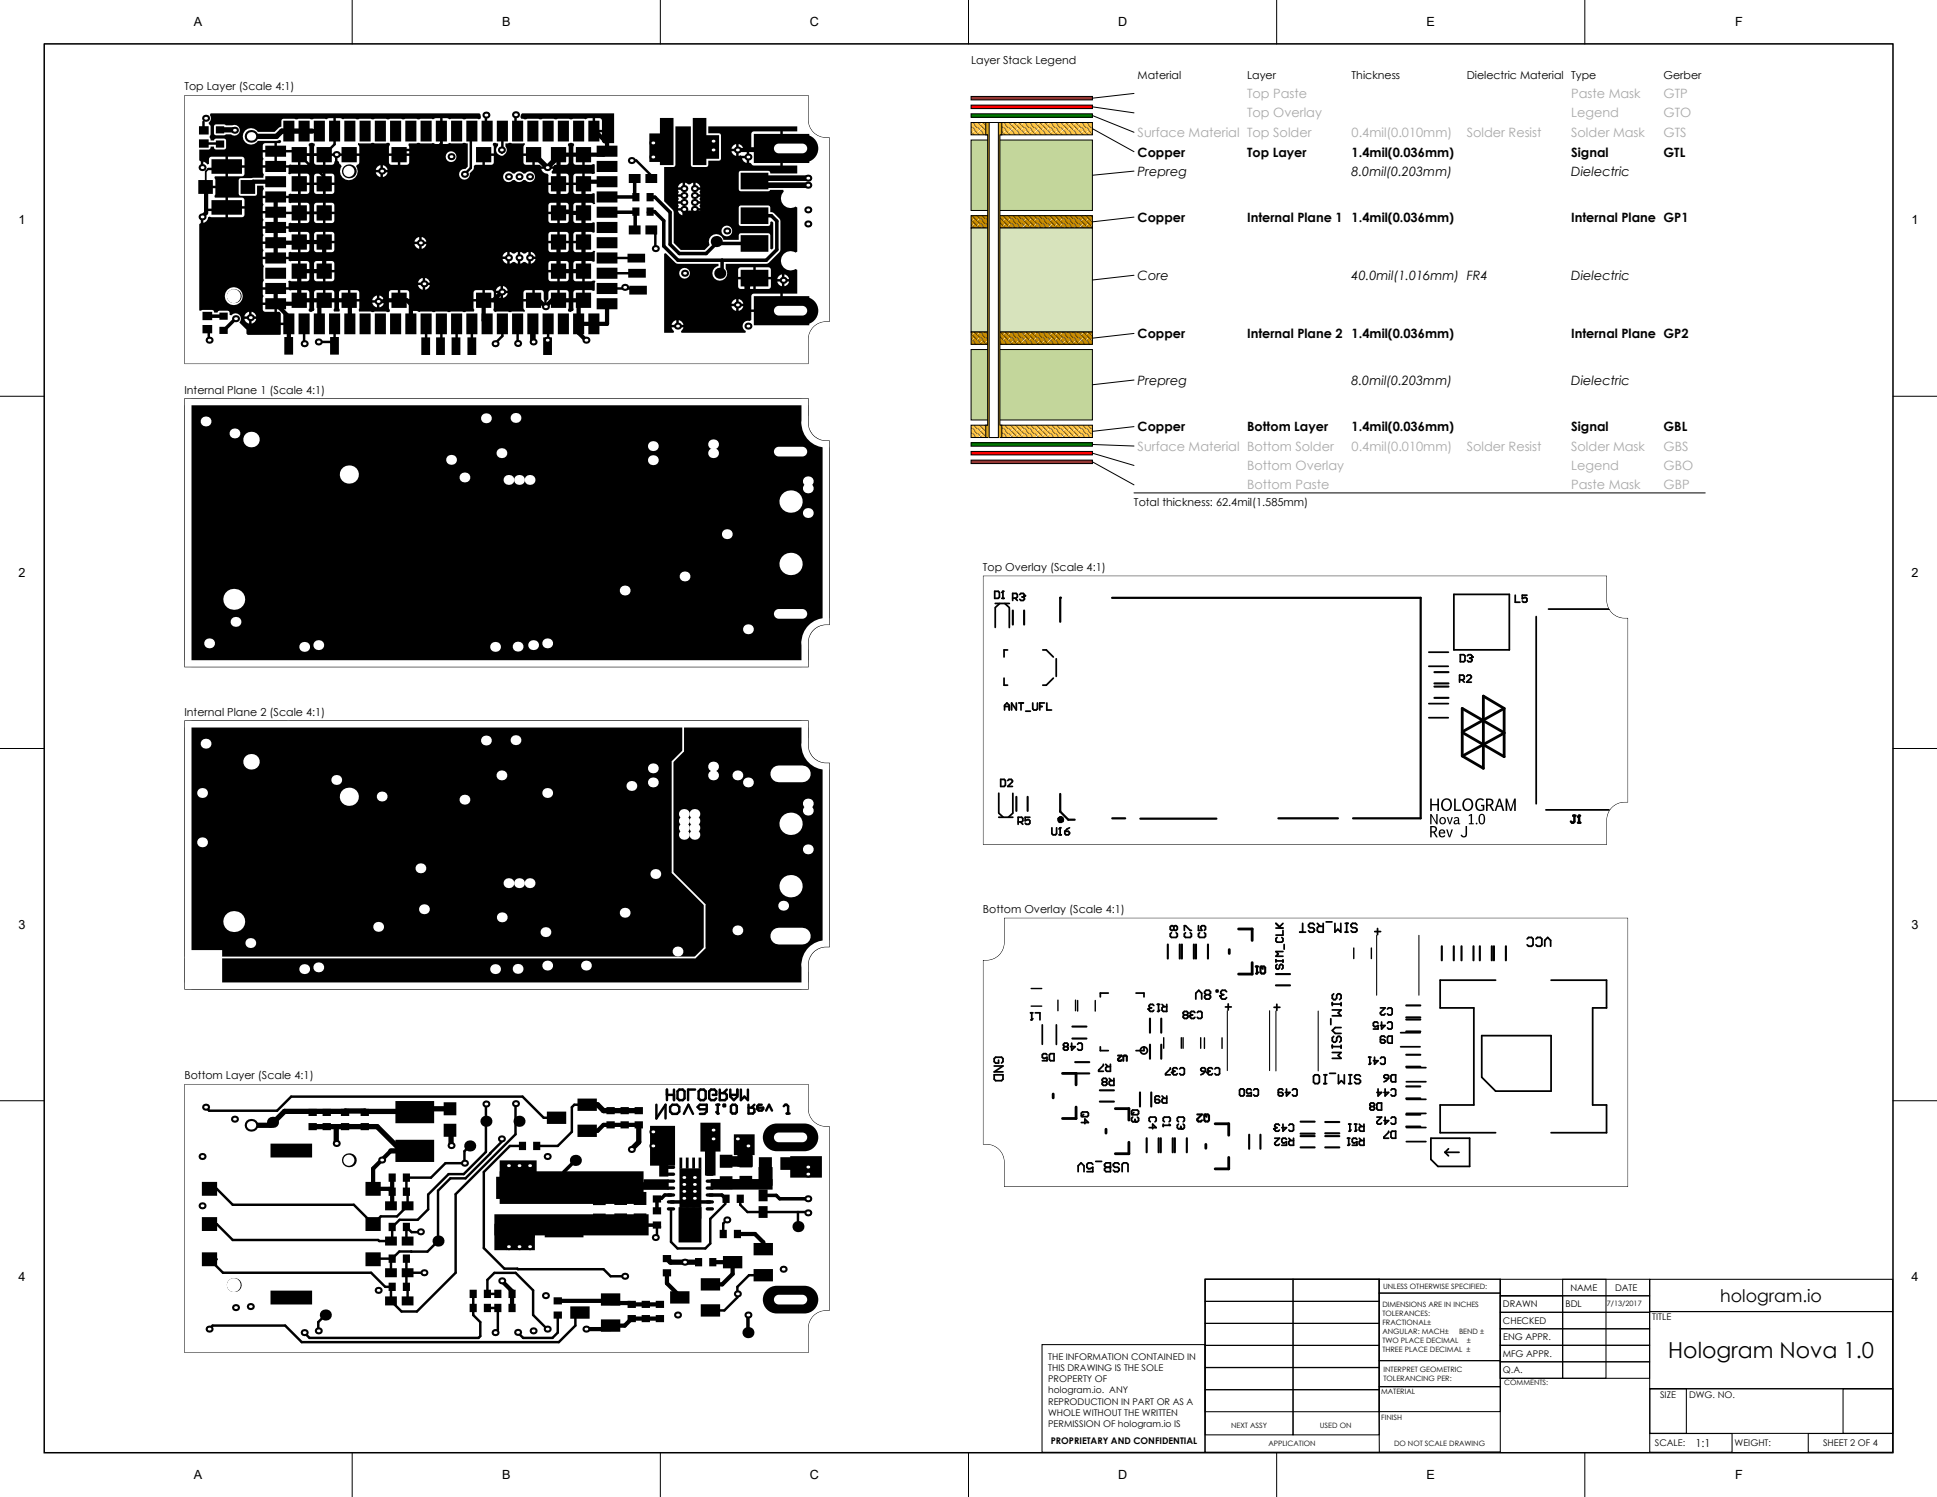
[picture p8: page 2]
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

CHECKED | | | TITLE Hologram Nova 1.0
ENG APPR.

THE INFORMATION CONTAINED IN THIS DRAWING IS THE SOLE | | | MFG APPR.

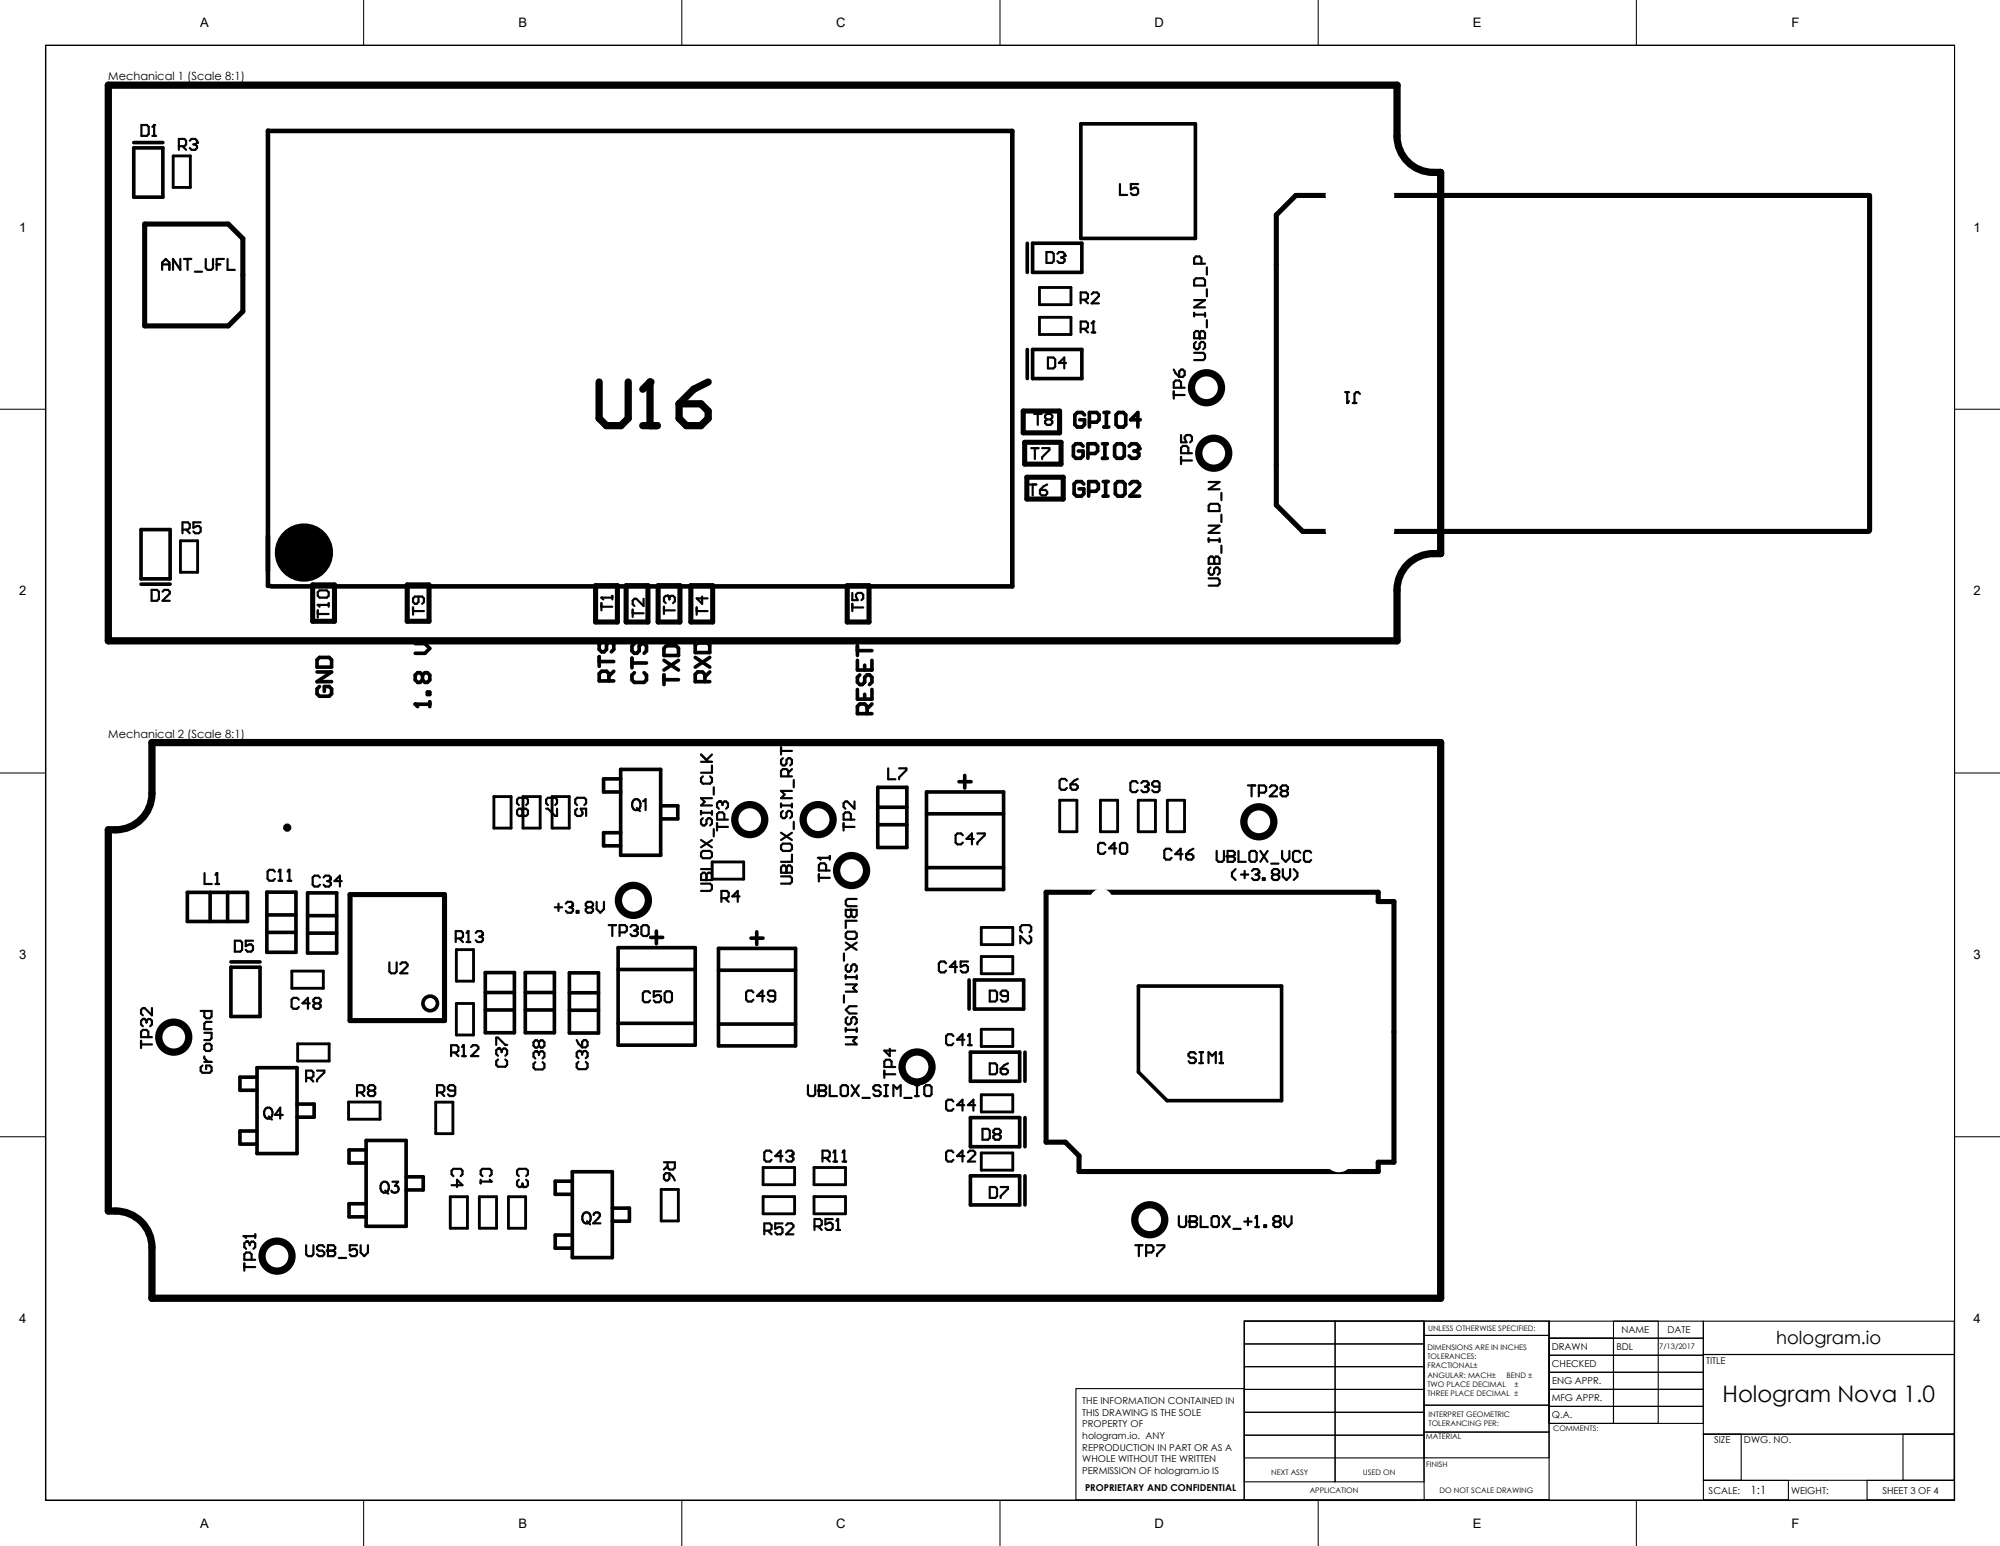
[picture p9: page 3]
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

CHECKED | | | TITLE Hologram Nova 1.0
ENG APPR.

THE INFORMATION CONTAINED IN THIS DRAWING IS THE SOLE | | | MFG APPR.

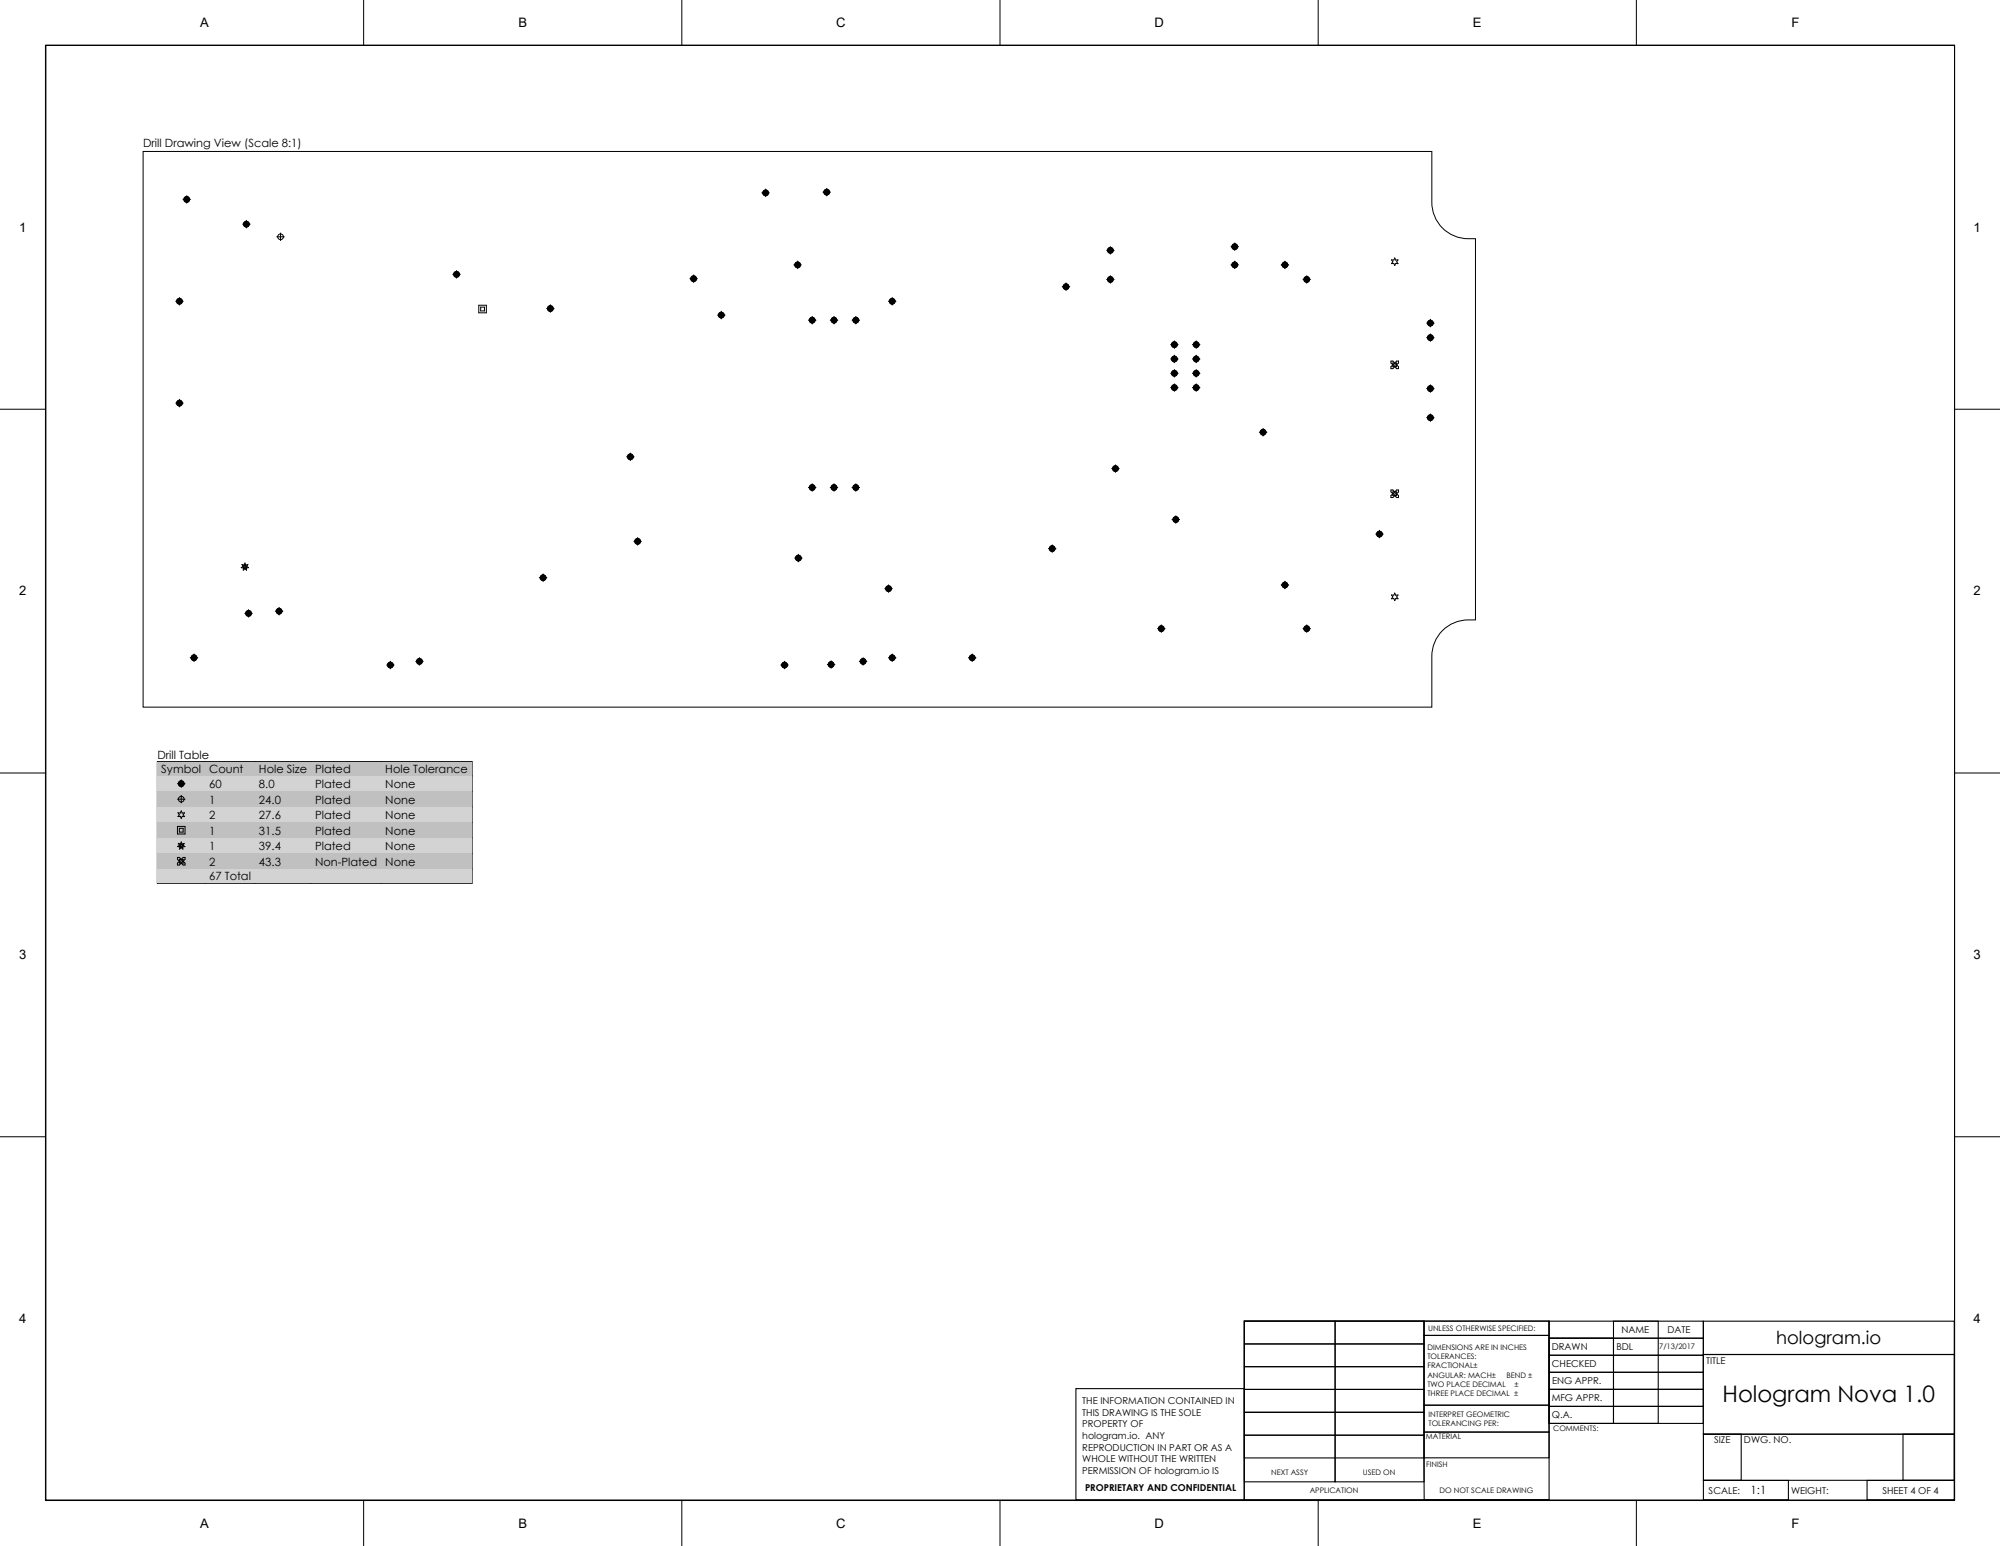
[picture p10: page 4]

Drill Drawing View (Scale 8:1)

Symbol | Count | Hole Size | Plated | Hole Tolerance

60 | 8.0 | Plated | None
1 | 24.0 | Plated | None
2 | 27.6 | Plated | None
1 | 31.5 | Plated | None
1 | 39.4 | Plated | None
2 | 43.3 | Non-Plated | None
67 Total

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

CHECKED | | | TITLE Hologram Nova 1.0
ENG APPR.

THE INFORMATION CONTAINED IN THIS DRAWING IS THE SOLE | | | MFG APPR.

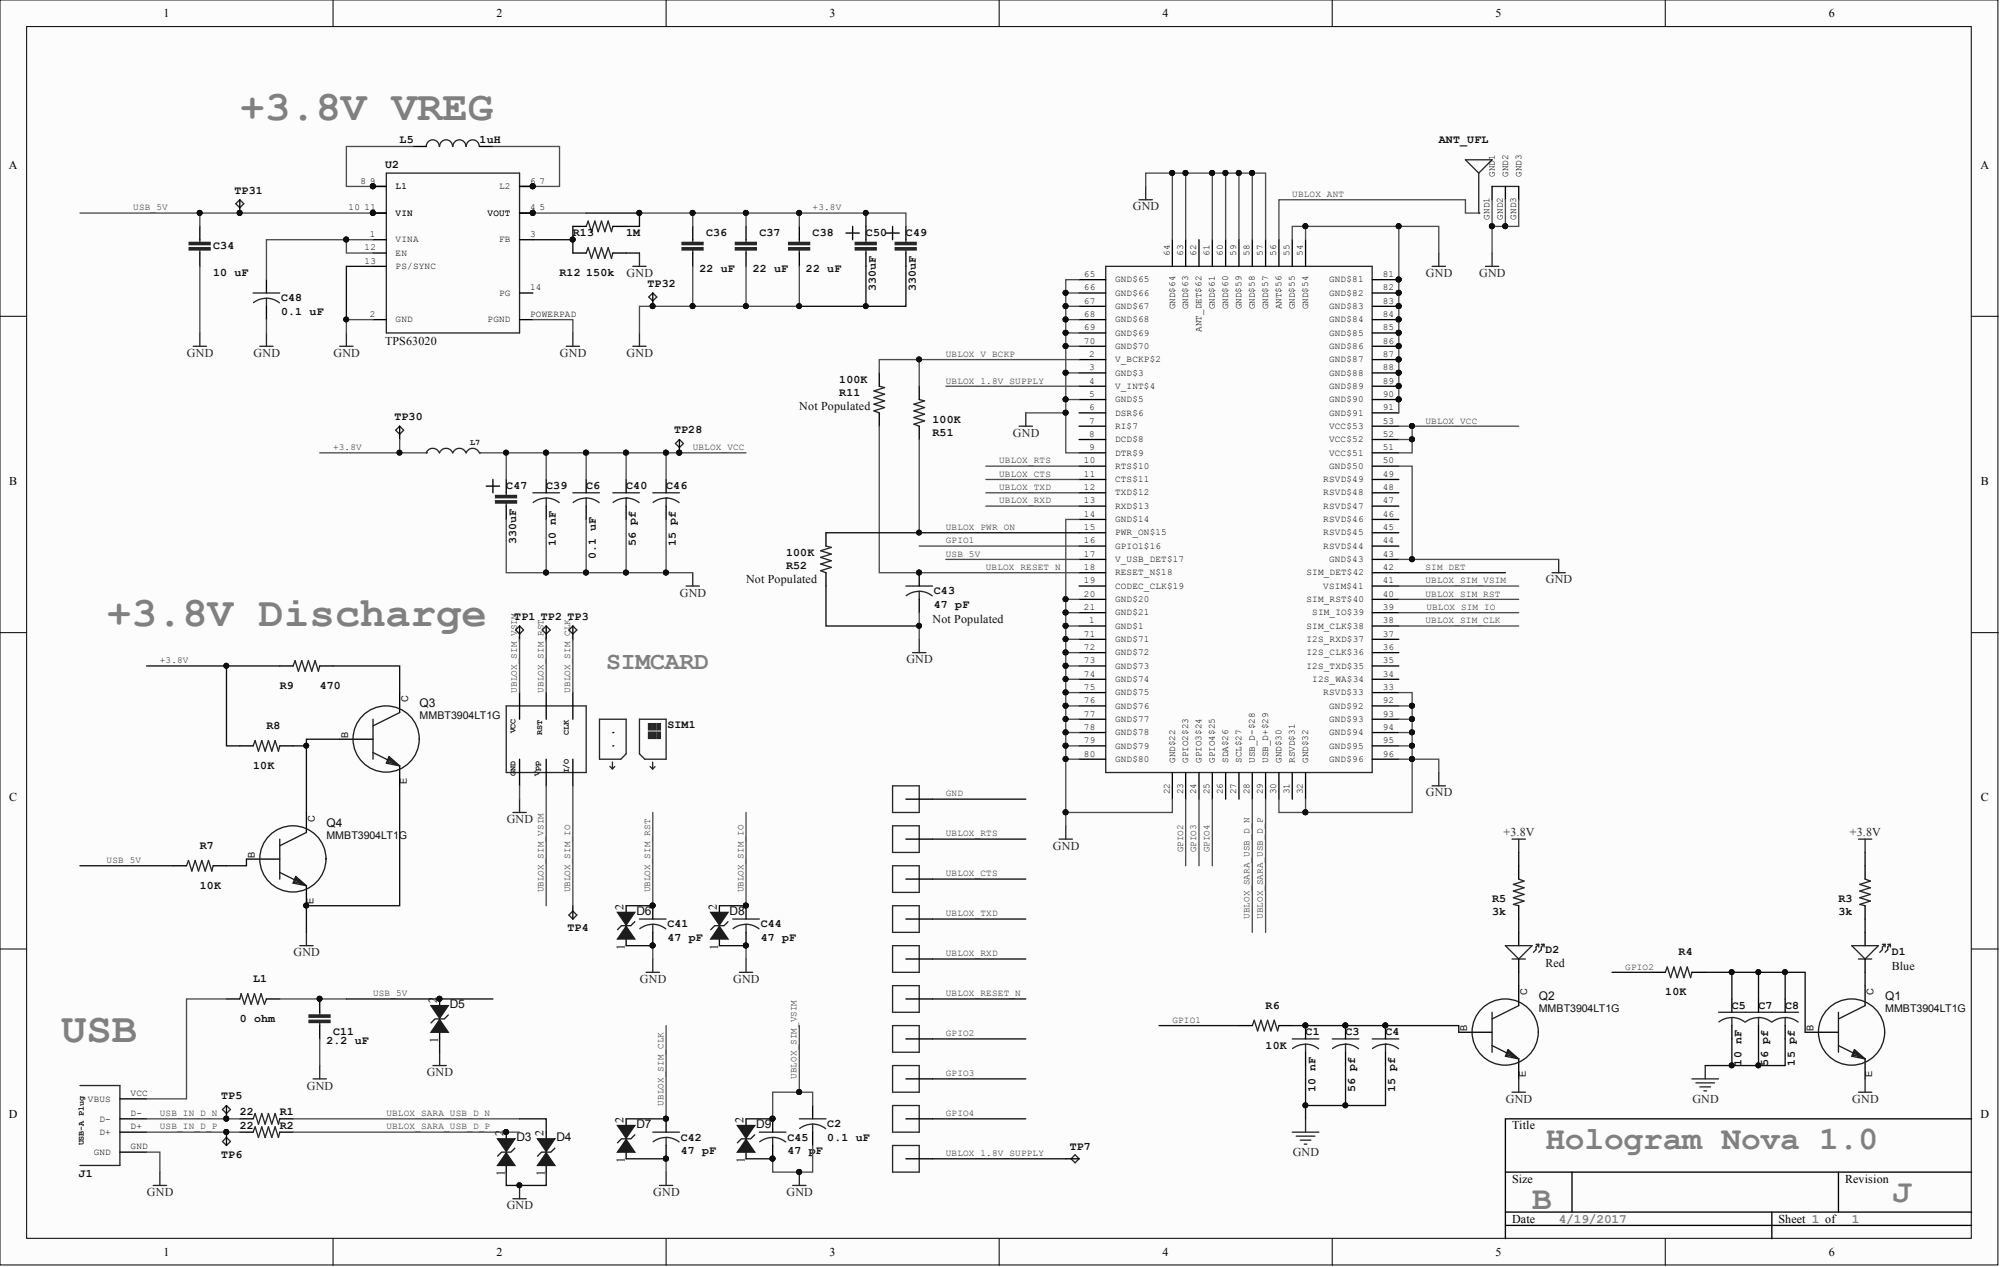
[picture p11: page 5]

GND$57 57 GND$58 58 GND$59 59 GND$60 60 GND$61 61

GND$3 3
V_INT$4 4 GND$5 5

PWR_ON$15 15

GPIO1 | | GPIO1$16 16

Size B | 1 | Revision 1 J 4/19/2017

Date | Sheet of

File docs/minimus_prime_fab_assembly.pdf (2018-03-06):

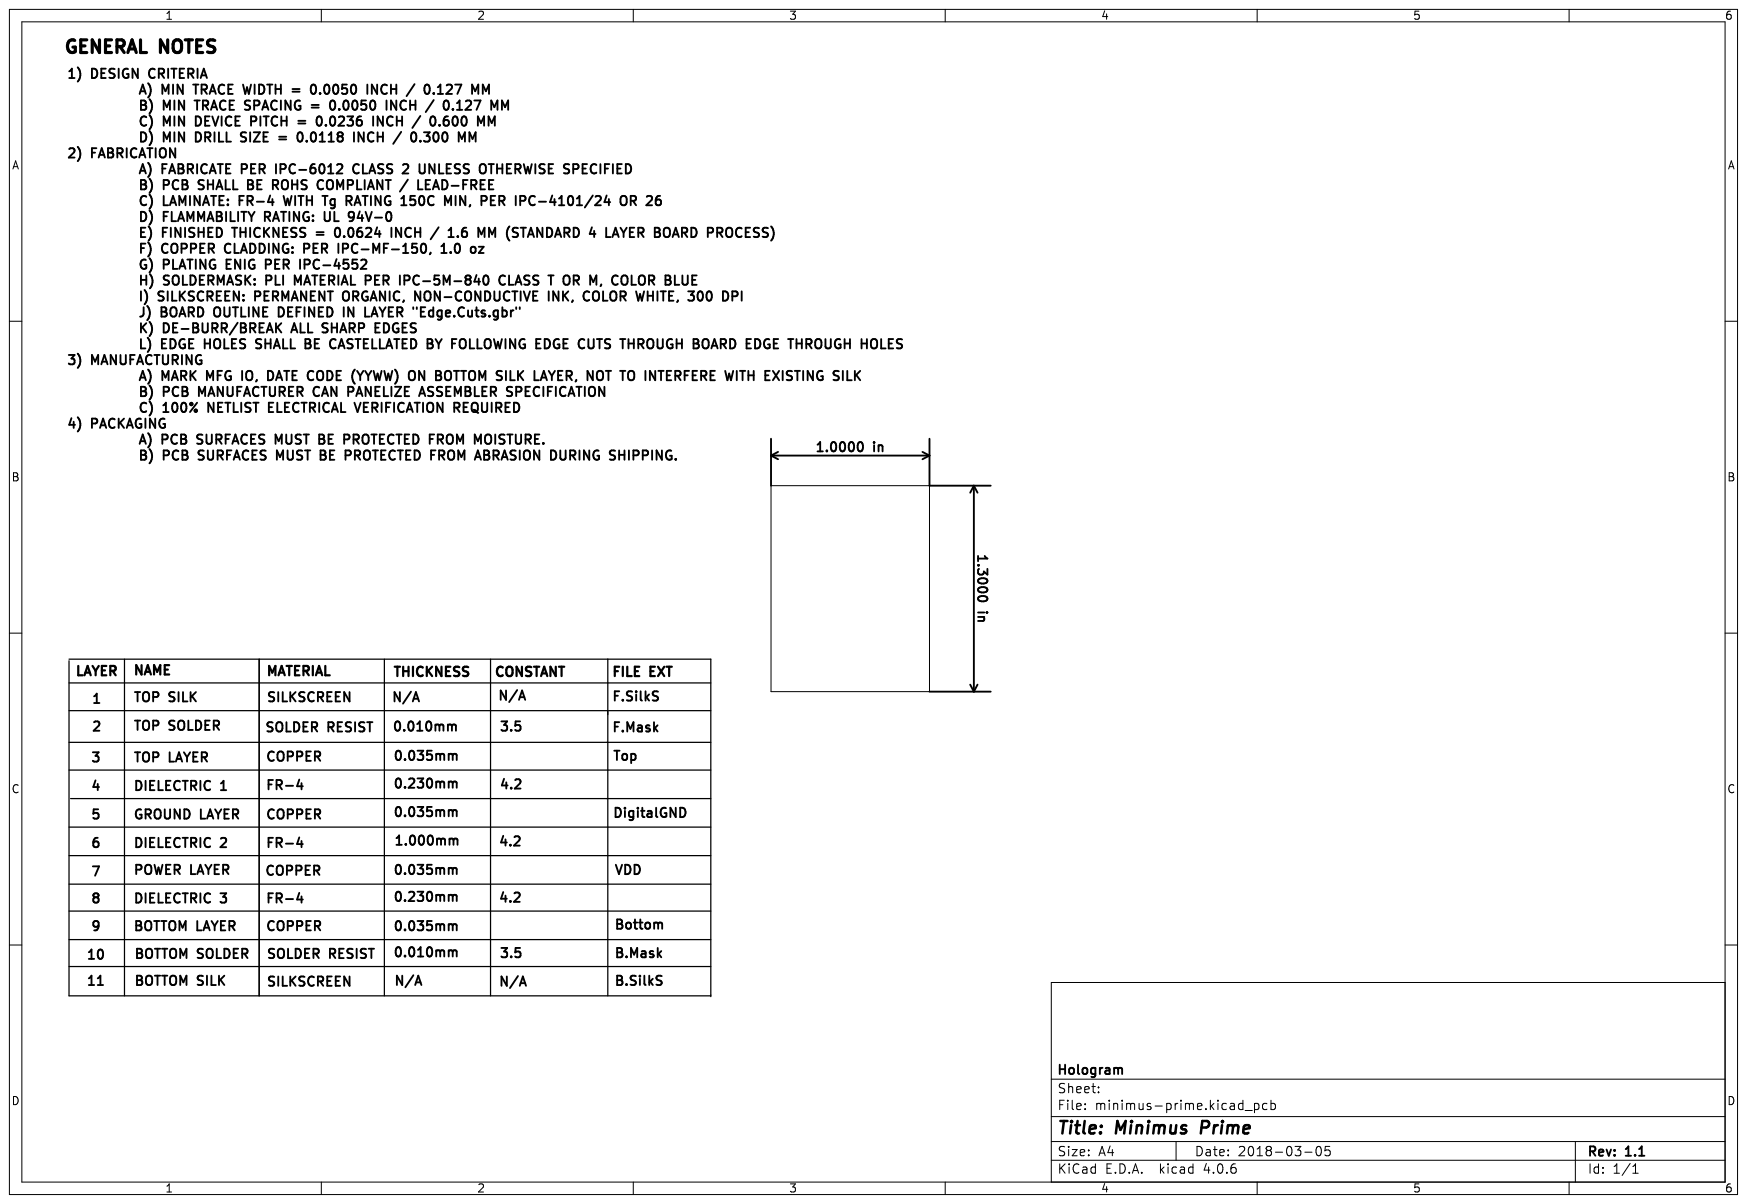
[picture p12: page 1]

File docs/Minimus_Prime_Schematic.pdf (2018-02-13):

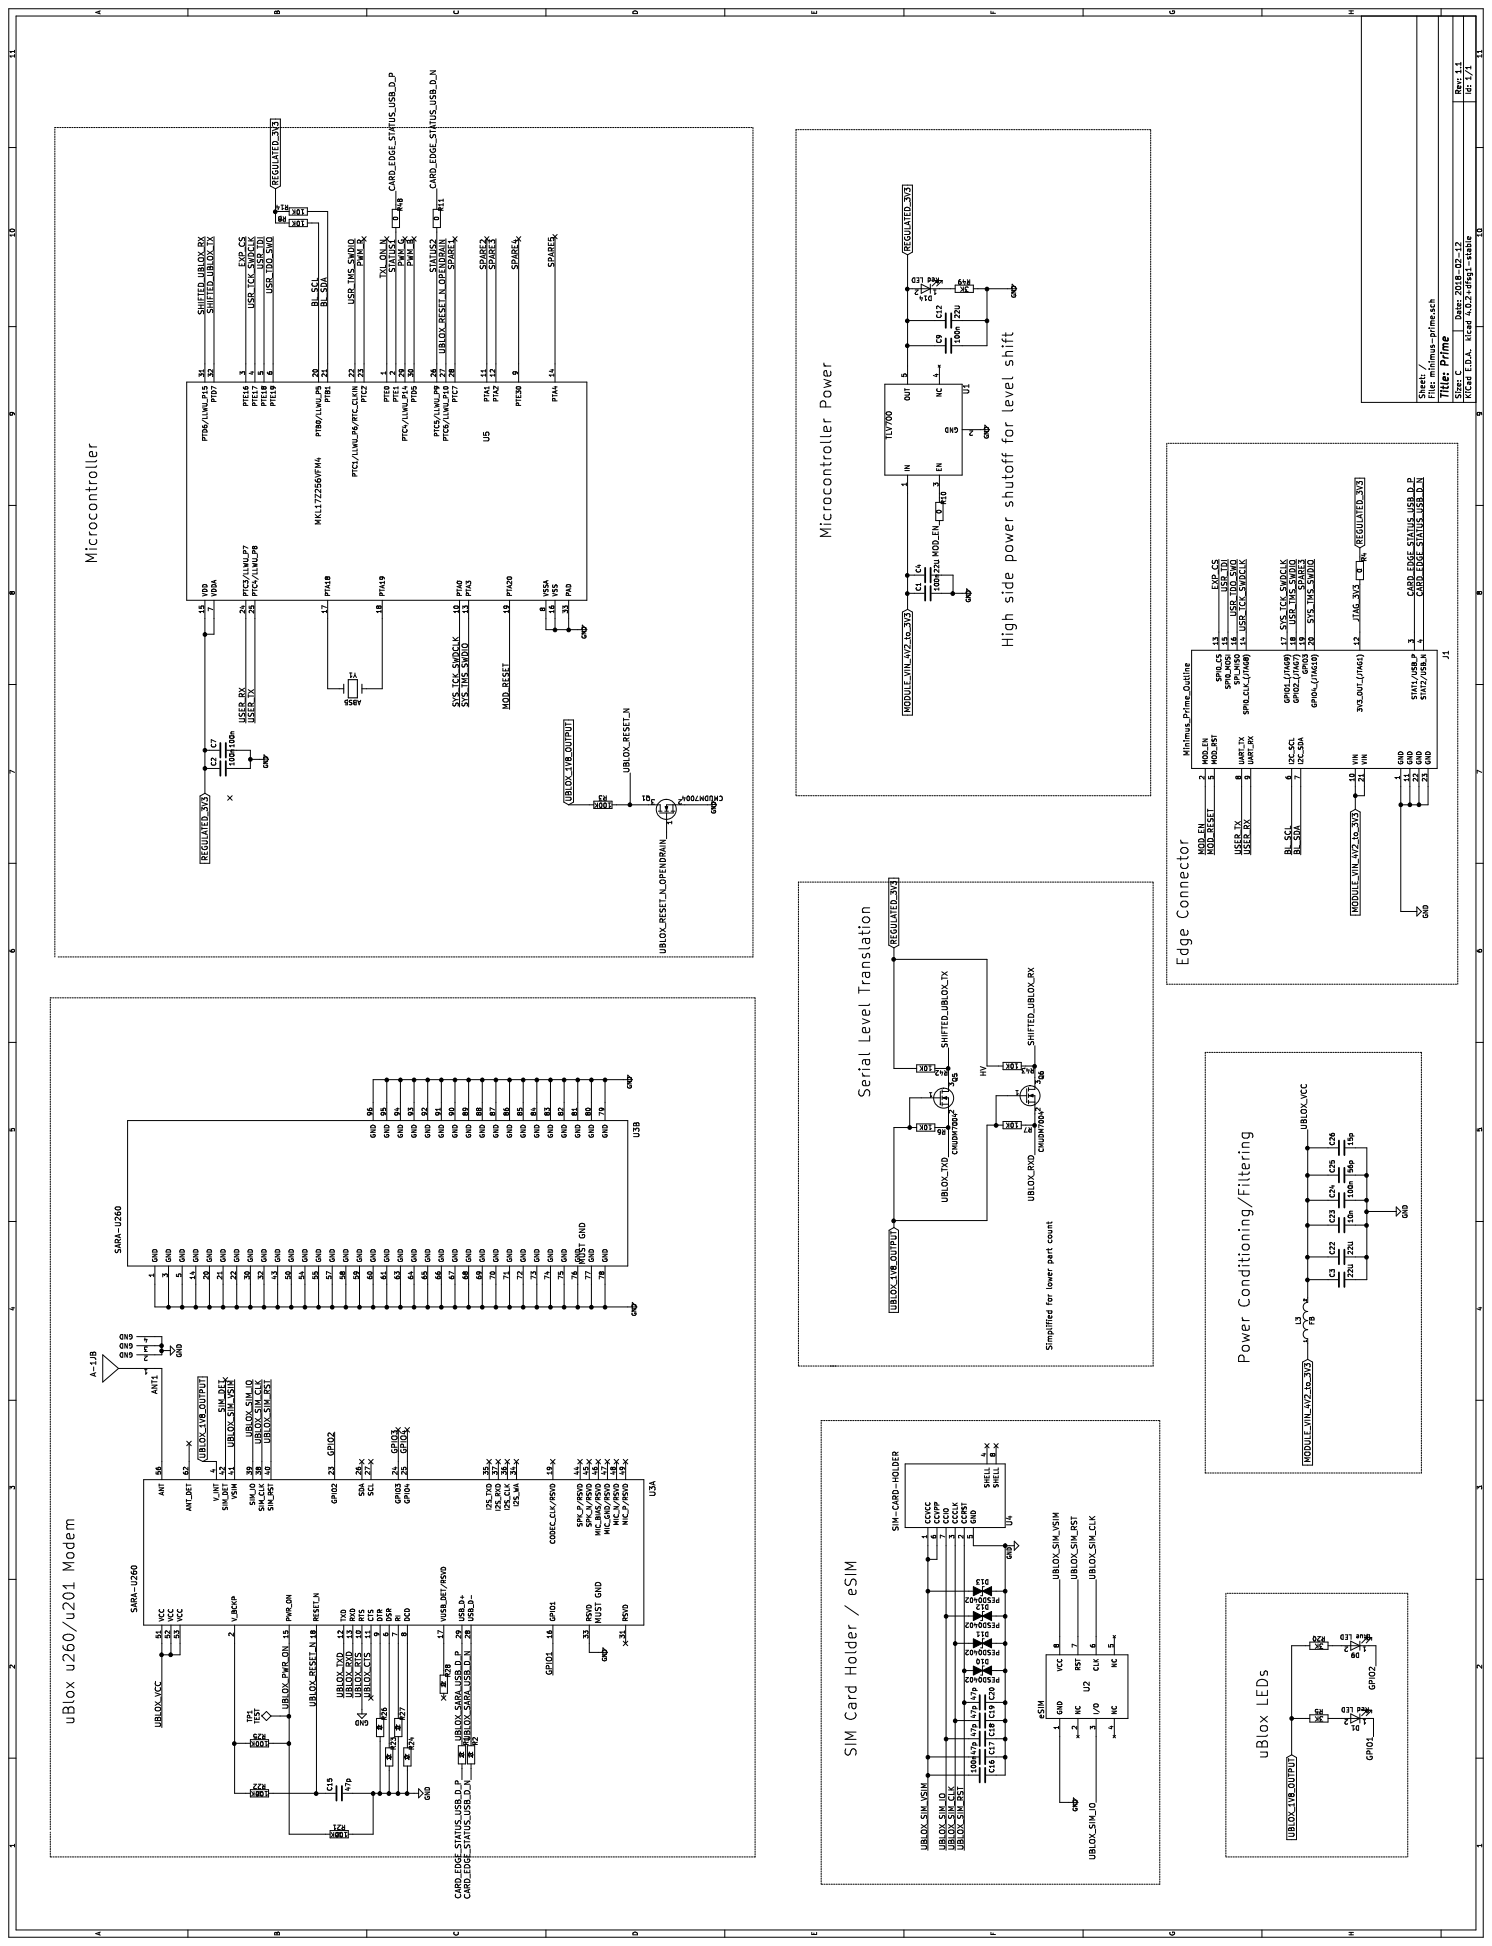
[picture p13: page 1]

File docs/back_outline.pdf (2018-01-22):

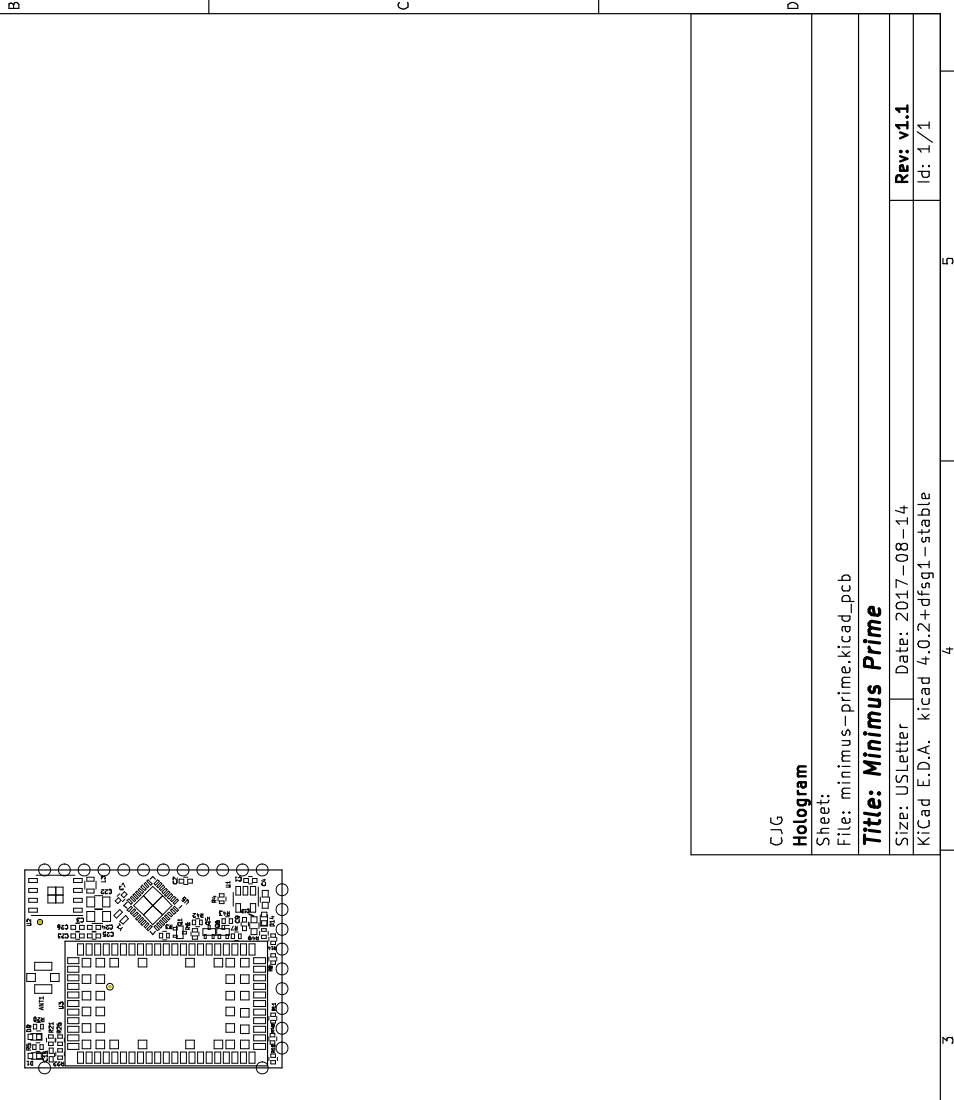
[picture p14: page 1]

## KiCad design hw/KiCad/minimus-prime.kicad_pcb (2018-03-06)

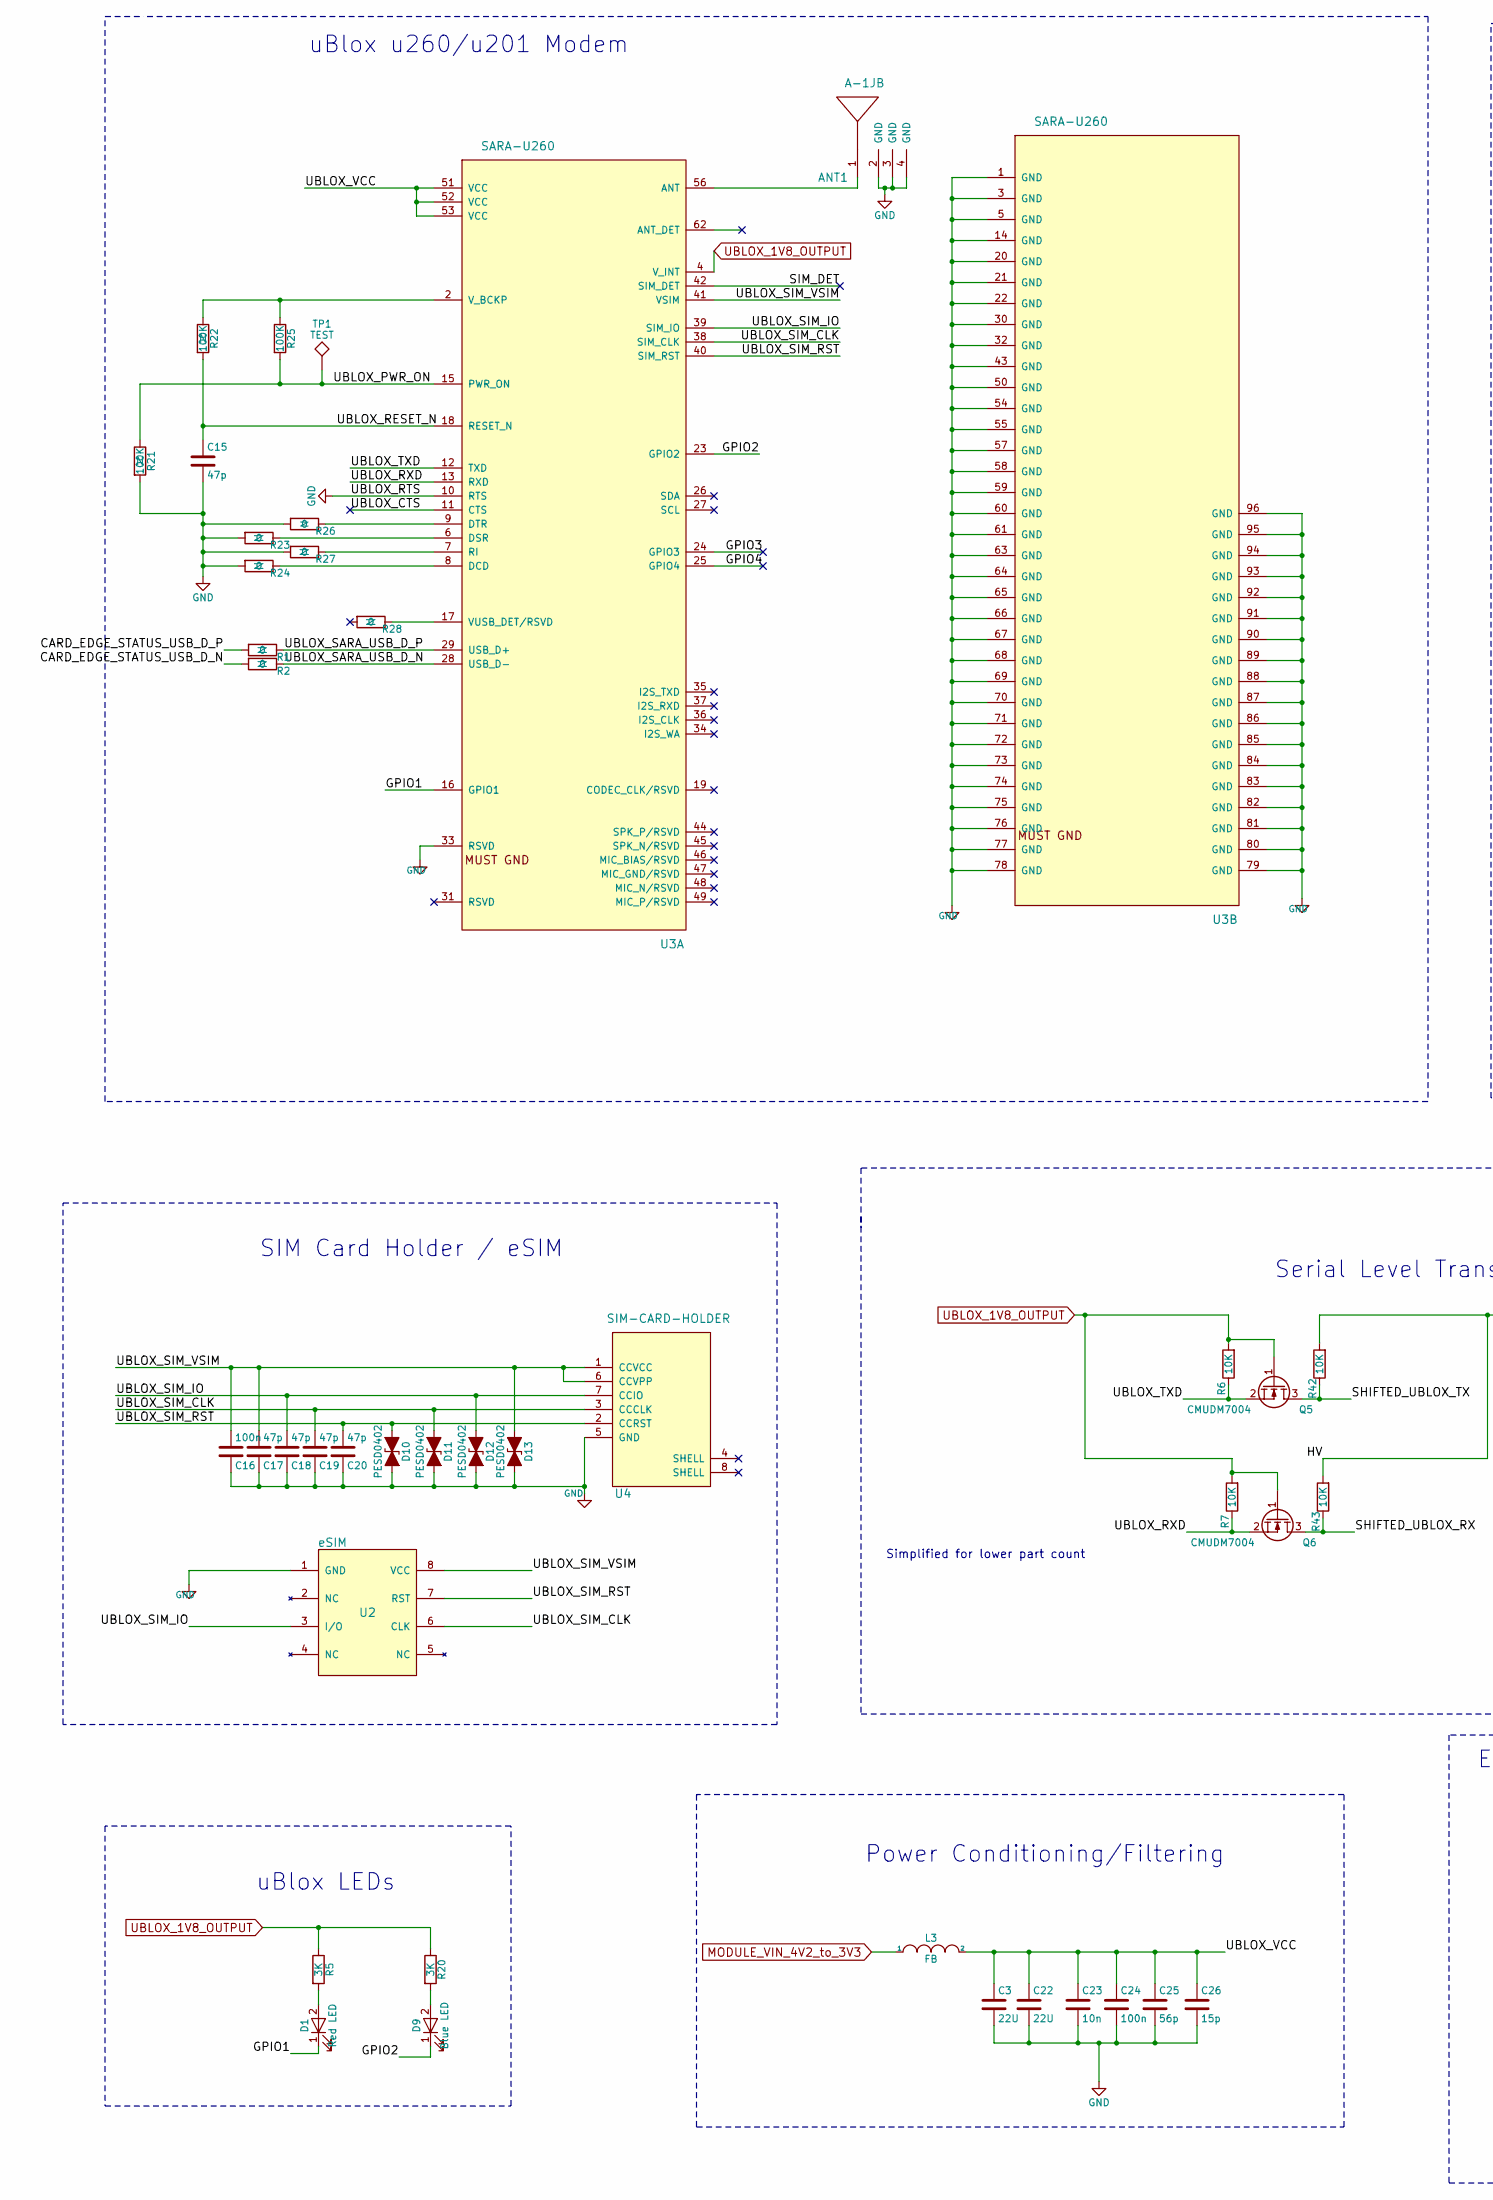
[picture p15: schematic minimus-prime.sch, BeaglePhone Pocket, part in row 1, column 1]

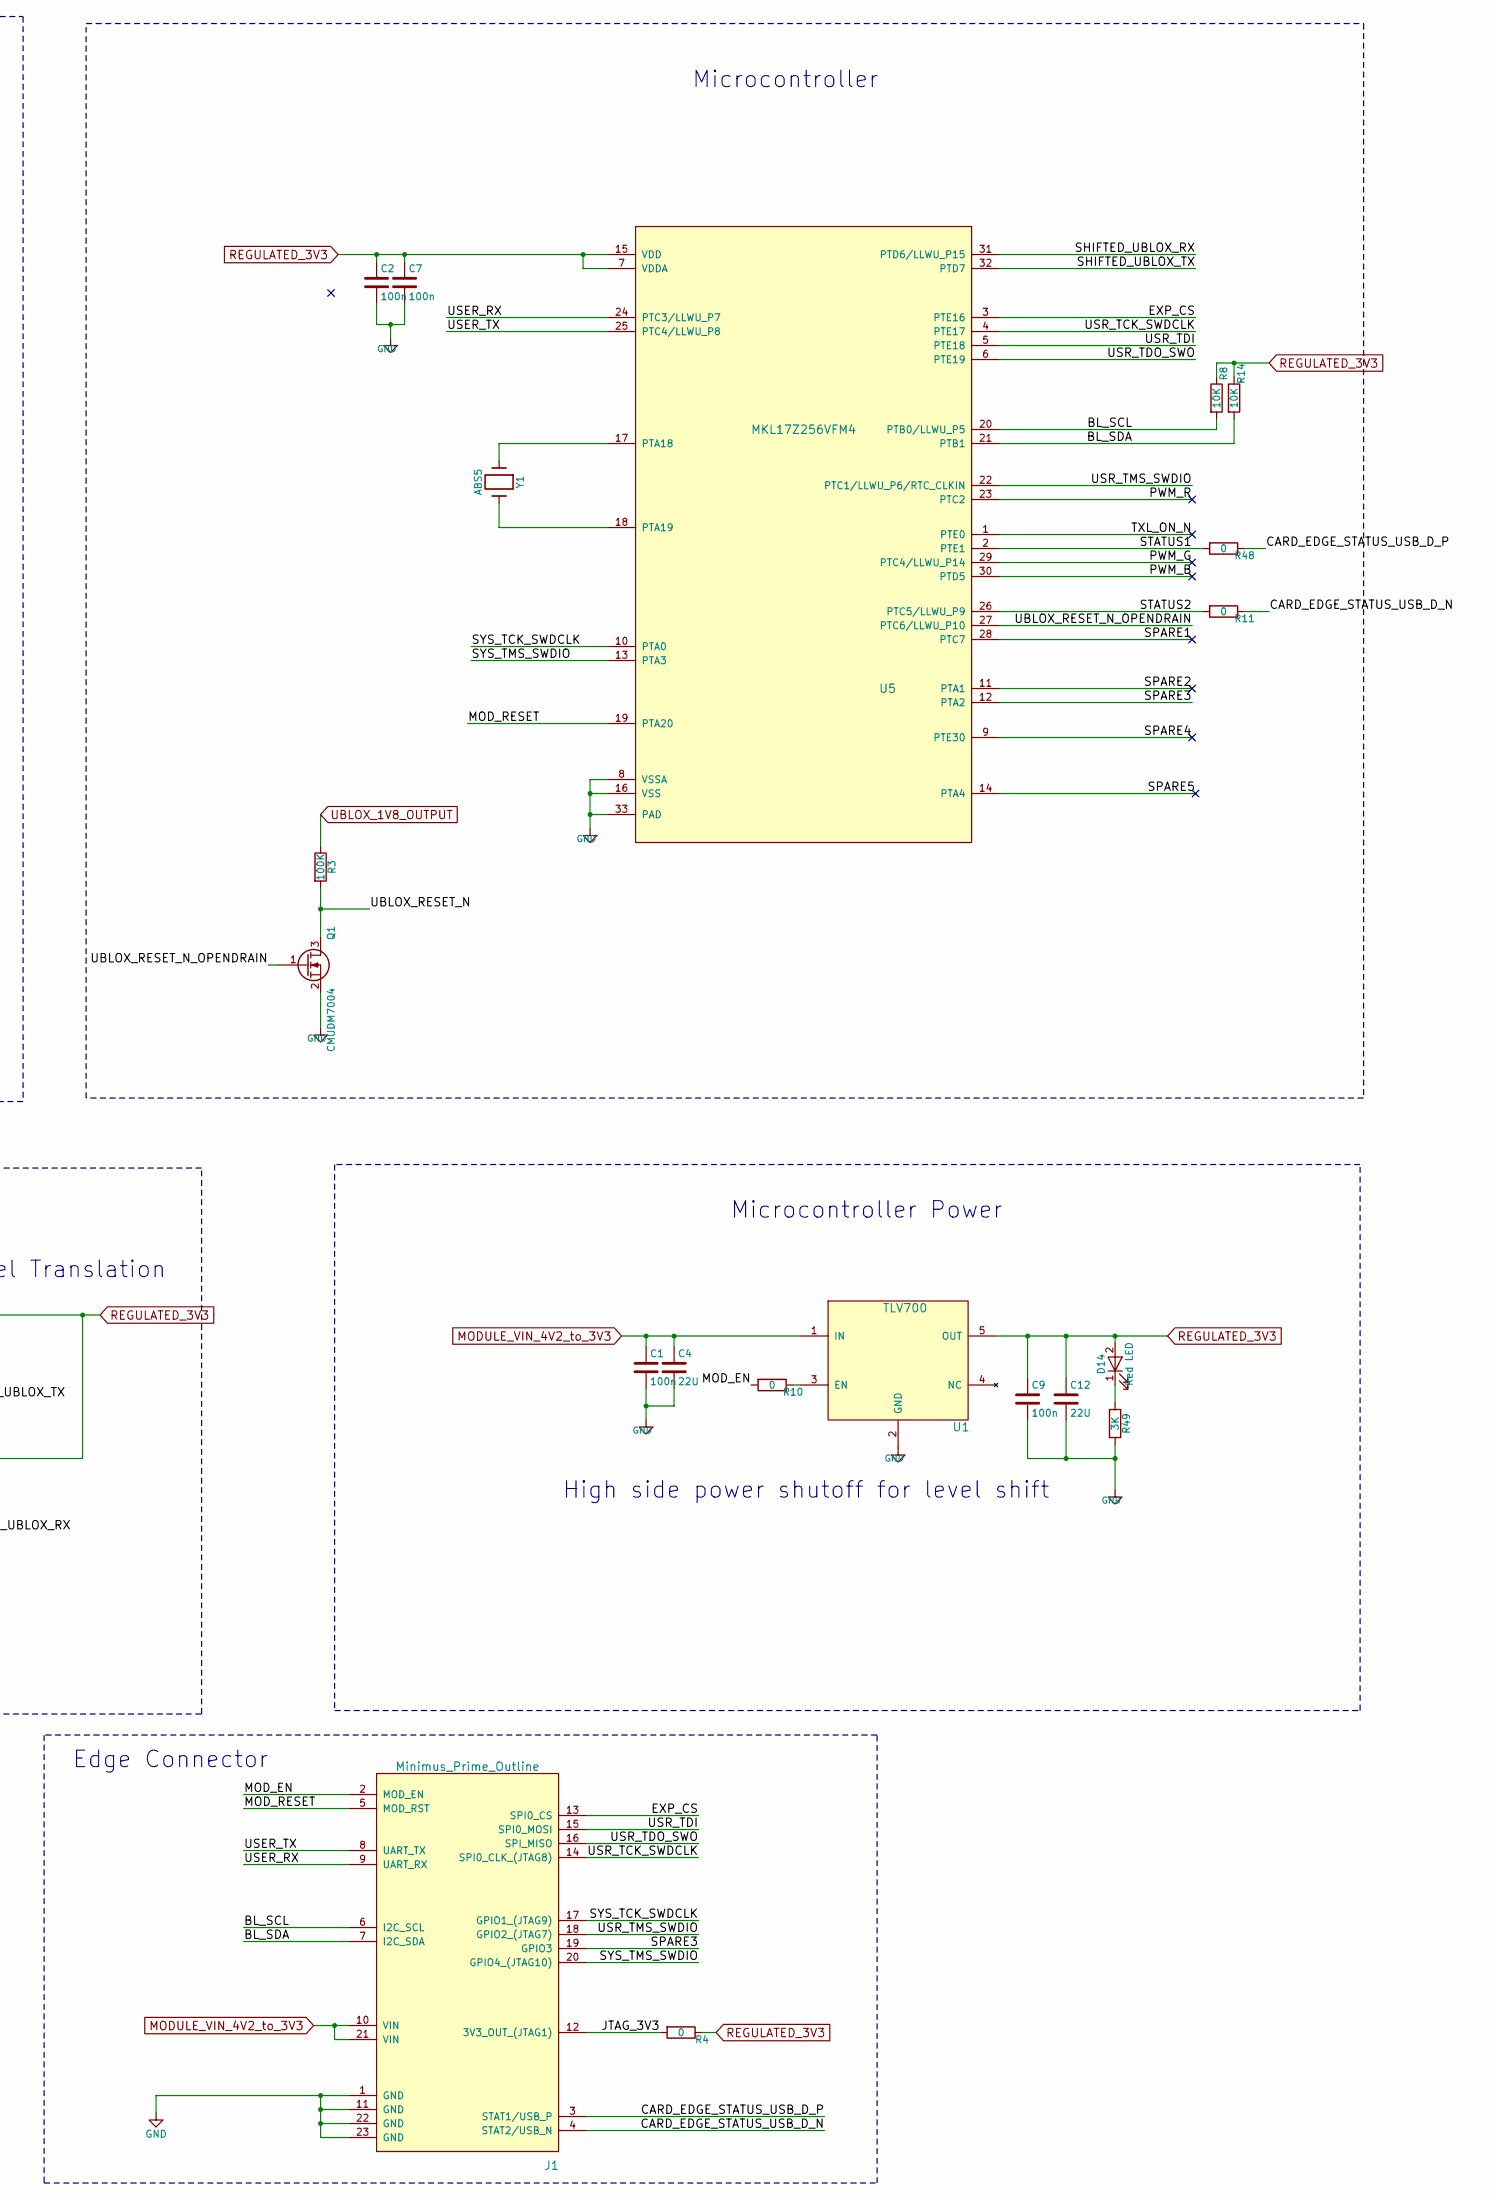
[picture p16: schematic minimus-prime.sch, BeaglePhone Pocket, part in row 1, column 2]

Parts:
ANT1: A-1JB; MPN A-1JB
C1, C2, C7, C9, C16, C24: 100n; C_0402; MPN GRM155R71C104KA88J
C3, C22: 22U; C_0805; MPN CL21A226MOCLRNC
C4, C12: 22U; C_0603; MPN GRM188R60J226MEA0D
C15, C17, C18, C19, C20: 47p; C_0402; MPN GRM1555C1H470JA01
C23: 10n; C_0402; MPN GRM1555C1H100JA01D
C25: 56p; C_0402; MPN GRM1555C1H560JA01D
C26: 15p; C_0402; MPN GJM1555C1H150JB01D
D1, D14: Red LED; LED_0402; MPN VLMS1500-GS08
D9: Blue LED; LED_0402; MPN VLMB1500-GS08
D10, D11, D12, D13: PESD0402; R_0402; MPN PESD0402-140
J1: Minimus_Prime_Outline
L3: FB; R_0603; MPN BLM18AG121SN1D
Q1, Q5, Q6: CMUDM7004; SOT-523; MPN CMUDM7004
R1, R2, R4, R10, R11, R23, R24, R26, R27, R28, R48: 0; R_0402; MPN RC0402JR-070RL
R3, R21, R22, R25: 100K; R_0402; MPN RC0402FR-07100KL
R5, R20, R49: 3K; R_0402; MPN RC0402JR-073KL
R6, R7, R8, R14, R42, R43: 10K; R_0402; MPN RC0402JR-0710KL
TP1: TEST
U1: TLV700; SOT-23-5; MPN TLV70033DDCR
U2: eSIM; DFN-8-1EP_6x5mm_Pitch1.27mm_SmallFlag; MPN eSIM
U3: SARA-U260; SARA-G3-U2; MPN SARA-U260-00S
U4: SIM-CARD-HOLDER; SIM8050-6-0-14-01-A; MPN SIM8050-6-0-14-01-A
U5: MKL17Z256VFM4; QFN-32-1EP_5x5mm_Pitch0.5mm; MPN MKL17Z256VFM4
Y1: ABS5; ABS05; MPN ABS05-32.768KHZ-T

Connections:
/BL_SCL: J1.6 (I2C_SCL), R8.2, U5.20 (PTB0/LLWU_P5)
/BL_SDA: J1.7 (I2C_SDA), R14.2, U5.21 (PTB1)
/CARD_EDGE_STATUS_USB_D_N: J1.4 (STAT2/USB_N), R2.2, R11.1
/CARD_EDGE_STATUS_USB_D_P: J1.3 (STAT1/USB_P), R1.2, R48.1
/EXP_CS: J1.13 (SPI0_CS), U5.3 (PTE16)
/GPIO1: D1.1 (K), U3.16 (GPIO1)
/GPIO2: D9.1 (K), U3.23 (GPIO2)
/GPIO3: U3.24 (GPIO3)
/GPIO4: U3.25 (GPIO4)
/MOD_EN: J1.2 (MOD_EN), R10.2
/MOD_RESET: J1.5 (MOD_RST), U5.19 (PTA20)
/PWM_B: U5.30 (PTD5)
/PWM_G: U5.29 (PTC4/LLWU_P14)
/PWM_R: U5.23 (PTC2)
/SHIFTED_UBLOX_RX: Q6.3 (D), R43.1, U5.31 (PTD6/LLWU_P15)
/SHIFTED_UBLOX_TX: Q5.3 (D), R42.1, U5.32 (PTD7)
/SIM_DET: U3.42 (SIM_DET)
/SPARE1: U5.28 (PTC7)
/SPARE2: U5.11 (PTA1)
/SPARE3: J1.19 (GPIO3), U5.12 (PTA2)
/SPARE4: U5.9 (PTE30)
/SPARE5: U5.14 (PTA4)
/STATUS1: R48.2, U5.2 (PTE1)
/STATUS2: R11.2, U5.26 (PTC5/LLWU_P9)
/SYS_TCK_SWDCLK: J1.17 (GPIO1_(JTAG9)), U5.10 (PTA0)
/SYS_TMS_SWDIO: J1.20 (GPIO4_(JTAG10)), U5.13 (PTA3)
/TXL_ON_N: U5.1 (PTE0)
/UBLOX_CTS: U3.11 (CTS)
/UBLOX_PWR_ON: R21.1, R25.2, TP1.1, U3.15 (PWR_ON)
/UBLOX_RESET_N: C15.1, Q1.3 (D), R3.2, R22.2, U3.18 (RESET_N)
/UBLOX_RESET_N_OPENDRAIN: Q1.1 (G), U5.27 (PTC6/LLWU_P10)
/UBLOX_RXD: Q6.2 (S), R7.1, U3.13 (RXD)
/UBLOX_SARA_USB_D_N: R2.1, U3.28 (USB_D-)
/UBLOX_SARA_USB_D_P: R1.1, U3.29 (USB_D+)
/UBLOX_SIM_CLK: C19.2, D11.1 (A1), U2.6 (CLK), U3.38 (SIM_CLK), U4.3 (CCCLK)
/UBLOX_SIM_IO: C18.2, D12.1 (A1), U2.3 (I/O), U3.39 (SIM_IO), U4.7 (CCIO)
/UBLOX_SIM_RST: C20.2, D10.1 (A1), U2.7 (RST), U3.40 (SIM_RST), U4.2 (CCRST)
/UBLOX_SIM_VSIM: C16.2, C17.2, D13.1 (A1), U2.8 (VCC), U3.41 (VSIM), U4.1 (CCVCC), U4.6 (CCVPP)
/UBLOX_TXD: Q5.2 (S), R6.1, U3.12 (TXD)
/UBLOX_VCC: C3.1, C22.1, C23.1, C24.1, C25.1, C26.1, L3.2, U3.51 (VCC), U3.52 (VCC), U3.53 (VCC)
/USER_RX: J1.9 (UART_RX), U5.24 (PTC3/LLWU_P7)
/USER_TX: J1.8 (UART_TX), U5.25 (PTC4/LLWU_P8)
/USR_TCK_SWDCLK: J1.14 (SPI0_CLK_(JTAG8)), U5.4 (PTE17)
/USR_TDI: J1.15 (SPI0_MOSI), U5.5 (PTE18)
/USR_TDO_SWO: J1.16 (SPI_MISO), U5.6 (PTE19)
/USR_TMS_SWDIO: J1.18 (GPIO2_(JTAG7)), U5.22 (PTC1/LLWU_P6/RTC_CLKIN)
GND: ANT1.2 (GND), ANT1.3 (GND), ANT1.4 (GND), C1.2, C2.2, C3.2, C4.2, C7.2, C9.2, C12.2, C15.2, C16.1, C17.1, C18.1, C19.1, C20.1, C22.2, C23.2, C24.2, C25.2, C26.2, D10.2 (A2), D11.2 (A2), D12.2 (A2), D13.2 (A2), J1.1 (GND), J1.11 (GND), J1.22 (GND), J1.23 (GND), Q1.2 (S), R21.2, R23.2, R24.2, R26.2, R27.2, R49.2, U1.2 (GND), U2.1 (GND), U3.1 (GND), U3.3 (GND), U3.5 (GND), U3.10 (RTS), U3.14 (GND), U3.20 (GND), U3.21 (GND), U3.22 (GND), U3.30 (GND), U3.32 (GND), U3.33 (RSVD), U3.43 (GND), U3.50 (GND), U3.54 (GND), U3.55 (GND), U3.57 (GND), U3.58 (GND), U3.59 (GND), U3.60 (GND), U3.61 (GND), U3.63 (GND), U3.64 (GND), U3.65 (GND), U3.66 (GND), U3.67 (GND), U3.68 (GND), U3.69 (GND), U3.70 (GND), U3.71 (GND), U3.72 (GND), U3.73 (GND), U3.74 (GND), U3.75 (GND), U3.76 (GND), U3.77 (GND), U3.78 (GND), U3.79 (GND), U3.80 (GND), U3.81 (GND), U3.82 (GND), U3.83 (GND), U3.84 (GND), U3.85 (GND), U3.86 (GND), U3.87 (GND), U3.88 (GND), U3.89 (GND), U3.90 (GND), U3.91 (GND), U3.92 (GND), U3.93 (GND), U3.94 (GND), U3.95 (GND), U3.96 (GND), U4.5 (GND), U5.8 (VSSA), U5.16 (VSS), U5.33 (PAD)
MODULE_VIN_4V2_to_3V3: C1.1, C4.1, J1.10 (VIN), J1.21 (VIN), L3.1, U1.1 (IN)
unnamed: ANT1.1, U3.56 (ANT)
unnamed: D1.2 (A), R5.2
unnamed: D9.2 (A), R20.2
unnamed: D14.1 (K), R49.1
unnamed: R10.1, U1.3 (EN)
unnamed: R22.1, R25.1, U3.2 (V_BCKP)
unnamed: R23.1, U3.6 (DSR)
unnamed: R24.1, U3.8 (DCD)
unnamed: R26.1, U3.9 (DTR)
unnamed: R27.1, U3.7 (RI)
unnamed: R28.1, U3.17 (VUSB_DET/RSVD)
unnamed: U5.17 (PTA18), Y1.1
unnamed: U5.18 (PTA19), Y1.2
UBLOX_1V8_OUTPUT: Q5.1 (G), Q6.1 (G), R3.1, R5.1, R6.2, R7.2, R20.1, U3.4 (V_INT)

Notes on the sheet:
Serial Level Translation
uBlox LEDs
uBlox u260/u201 Modem
SIM Card Holder / eSIM
Power Conditioning/Filtering
High side power shutoff for level shift
Simplified for lower part count
Edge Connector
Microcontroller Power
Microcontroller

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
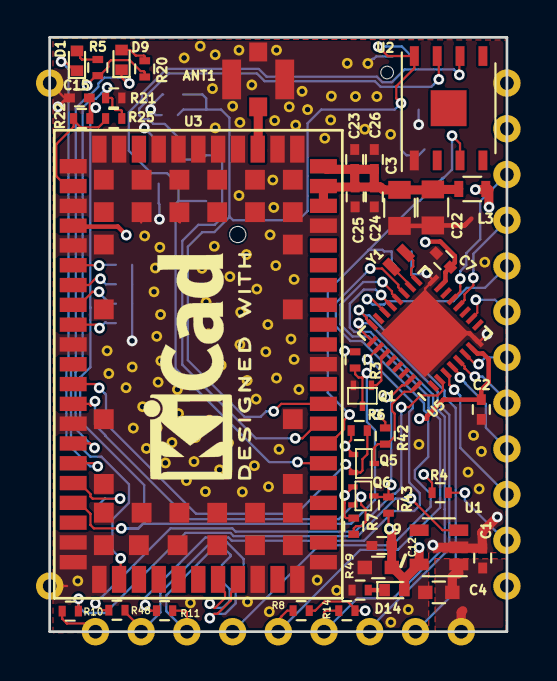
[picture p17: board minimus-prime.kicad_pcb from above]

Board: 4 copper layers, 25.4 x 33.0 mm, 61 parts (0 on the bottom side), 52 nets.

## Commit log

2018-01-20 Pulled in old file (renamed) from the beaglephone-pocket project
    [minimus-prime.kicad_pcb, minimus-prime.sch]
2018-01-20 Added m0 and linear reg to schematic
    [minimus-prime.sch]
2018-01-20 Started adding signal names
    [minimus-prime.sch]
2018-01-20 Annotated schematic for new components
    [minimus-prime.sch]
2018-01-20 Assigned footprints (not final) to get initial fitting
    [_saved_minimus-prime.sch, minimus-prime.sch]
2018-01-20 Added another LED and generated initial netlist
    [_saved_minimus-prime.sch, minimus-prime.sch]
2018-01-20 Added a left and right 01x14 connector and a 01x08 connector to simulate edge connections
    [minimus-prime.kicad_pcb, minimus-prime.sch]
2018-01-20 Decided to move board out by an additional .1 inch, total dimensions now roughly 1.1x1.4
    [minimus-prime.sch]
2018-01-20 Preliminary pinout for card edge
    [minimus-prime.kicad_pcb, minimus-prime.sch]
2018-01-20 Started creating power zones
    [minimus-prime.kicad_pcb, minimus-prime.sch]
2018-01-21 Got rid of 330 uF cap
    [minimus-prime.kicad_pcb, minimus-prime.sch]
2018-01-21 Switching to SOT523 part for level shifter
    [minimus-prime.kicad_pcb, minimus-prime.sch]
2018-01-21 Removed a bunch of level shifter parts
    [minimus-prime.sch]
2018-01-21 Started routing final data lines
    [minimus-prime.kicad_pcb, minimus-prime.sch]
2018-01-21 Removed USB components and connections
    [minimus-prime.sch]
2018-01-21 First pass placement done, layout in final stages, off for schematic review
    [minimus-prime.kicad_pcb, minimus-prime.sch]
2018-01-21 Almost finished routing early board, updating from Ben L's suggestions
    [minimus-prime.kicad_pcb]
2018-01-21 Implemented some of the changes, lengthend the card edge
    [minimus-prime.sch]
2018-01-21 Created another plane for module Vin
    [minimus-prime.kicad_pcb]
2018-01-21 Changed net names for clarity
    [minimus-prime.kicad_pcb, minimus-prime.sch]
2018-01-21 Added open drain FET for reset line
    [Hologram Dash BOM.xlsx, minimus-prime.kicad_pcb, minimus-prime.sch]
2018-01-21 Finished routing power to micro
    [minimus-prime.kicad_pcb]
2018-01-21 Added 3V3 to card edge for JTAG
    [minimus-prime.kicad_pcb, minimus-prime.sch]
2018-01-21 Added markers for external pins
    [minimus-prime.kicad_pcb, minimus-prime.sch]
2018-01-21 Added silkscreen logo, started DRC
    [minimus-prime.kicad_pcb]
2018-01-21 Removed all orginal DRC errors
    [minimus-prime.kicad_pcb]
2018-01-21 Changed name of external reset (mod_reset) and hooked into the previous pushbutton pin
    [minimus-prime.kicad_pcb, minimus-prime.sch]
2018-01-21 Swapped some pins to preserve PWM pins for adding a tricolor LED in the future
    [minimus-prime.kicad_pcb, minimus-prime.sch]
2018-01-21 Added all silkscreen logos
    [minimus-prime.kicad_pcb]
2018-01-21 Hid all the info layers
    [minimus-prime.kicad_pcb]
2018-01-22 Added Gerbers, converted old BOM
    [Hologram Dash BOM.ods, Hologram Dash BOM.xlsx]
2018-01-22 Broken trace found by fab house, good lord
    [minimus-prime.kicad_pcb]
2018-01-22 Generated gerbers for v1.1
    [minimus-prime-B.Mask.gbr, minimus-prime-B.Paste.gbr, minimus-prime-B.SilkS.gbr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]
2018-01-22 Print to US letter sized paper for scaling
2018-01-23 Added eagle footprint
2018-01-25 exported csv using kifield
    [minimus-prime.csv]
2018-01-25 Updated population for parts on the board using kifield
    [minimus-prime.csv, minimus-prime.sch]
2018-02-05 Added a new symbol to represent the module edge
    [_saved_minimus-prime.sch]
2018-02-05 Changed revision number and updated edge connector
    [_saved_minimus-prime.sch, minimus-prime.sch]
2018-02-05 Moved Eagle and KiCad to a hw folder for top level consistency
    [minimus-prime-B.Mask.gbr, minimus-prime-B.Paste.gbr, minimus-prime-B.SilkS.gbr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]
2018-02-07 removed old csv files and generated a new one
    [minimus-prime.csv]
2018-02-07 updated BOM with combined parts and placement data
    [minimus-prime.csv, minimus-prime.sch]
2018-02-13 Changed notes on schematic page
    [minimus-prime.sch]
2018-02-13 Generated package including placement data and schematic
2018-03-06 Added fab drawings to the DWG layer and generated docs for fabrication
    [minimus-prime.kicad_pcb]
